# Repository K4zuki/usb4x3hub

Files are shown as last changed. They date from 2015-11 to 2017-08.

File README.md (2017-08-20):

# C92で購入いただいた方へ
- この本のPDFファイルは
  [こちら](https://github.com/K4zuki/usb4x3hub/releases/tag/c92-print-out)
- この本に登場する基板のデータは
  [こちら](https://github.com/K4zuki/usb4x3hub/releases/tag/r0.5-gerber-out)
- 秋月メモリ液晶基板の本は[こちら](https://github.com/K4zuki/AkiSpiLcd)です

# このリポジトリは何
コミケ９２に向けて書いていた本の原稿と、同時頒布を目指して設計を進めていた
基板の設計データです。原稿はmarkdownで書かれています。 設計データは
Eagle７系のbrdファイルとガーバデータです。

# USB4x3HUB: connects 4 USB hosts to share 3-port USB HUB
If you have **PCs, MACs, LINUXes, XBOXes and/or PS4s**, you can share your favorite Keyboard and Mouse (and one more)

> NOTE: I do not have PS4 so it is not tested;USB4x3HUB might not work with PS4

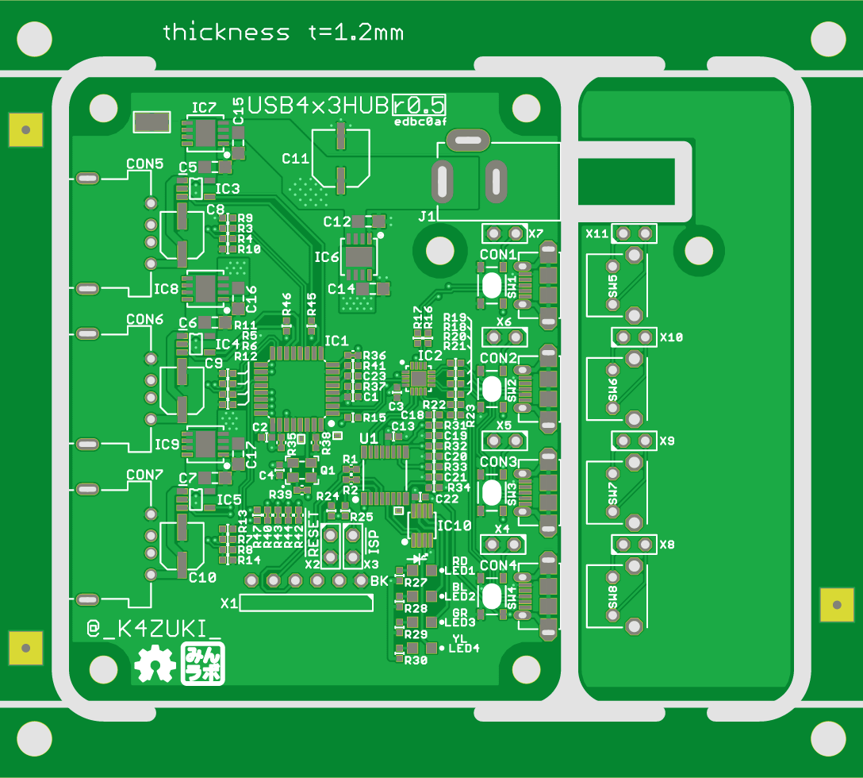
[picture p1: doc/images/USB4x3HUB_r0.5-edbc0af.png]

**rev 0.5 - みんなのラボ brand**

<!-- ![](doc/images/USB4x3HUBr1.png)
**rev 0.1** -->

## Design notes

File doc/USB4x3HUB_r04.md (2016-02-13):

| Qty | Value | Parts | Description | AKIZUKI | DIGIKEY | MOUSER | NOT_COMPONENT | SEEED |
|:---|:---|:---|:---|:---|:---|:---|:---|:---|
| 1 | TSW-106-02-S-S-RA | X1 | HEADER RIGHT ANGLE | C-05336 | 952-2372-ND | | | |
| 3 | USB A CONNECTOR | CON5-7 | USB A CONNECTOR | C-07674 | UE27AC54100-ND | | | |
| 1 | RD | LED1 | LED | I-06419 | 160-1168-1-ND | | | |
| 1 | YL | LED4 | LED | I-06420 | 160-1170-1-ND | | | |
| 1 | GR | LED3 | LED | I-06423 | 160-1169-1-ND | | | |
| 1 | BL | LED2 | LED | I-06424 | 160-1643-1-ND | | | |
| 1 | RD | SW1 | 2P tact switch | P-08213 | 679-2452-ND | | | |
| 1 | BL | SW2 | 2P tact switch | P-08214 | 679-2452-ND | | | |
| 1 | GR | SW3 | 2P tact switch | P-08215 | 679-2452-ND | | | |
| 1 | YL | SW4 | 2P tact switch | P-08216 | 679-2452-ND | | | |
| 1 | SN74LVC1G139DCUR | IC10 | single 74 logic: 139 | | 296-18235-1-ND | | | |
| 3 | 5V | IC7-9 | LDO with 4 pins | | 296-19663-1-ND | 595-TLV1117-50CDRJR | | |
| 1 | TUSB2036 | IC1 | 2/3-port USB hub IC | | 296-27129-1-ND | | | |
| 1 | 3.3V | IC6 | LDO with 4 pins | | 296-32364-1-ND | | | |
| 3 | TPS2041C | IC3-5 | power switch | | 296-35520-1-ND | | | |
| 2 | test points | TP1/2 | test points | | 36-5019CT-ND | | | |
| 10 | 0.1u/1005 | C1-4, C13, C18-22 | SMD CAPACITOR | | 490-3261-1-ND | | | 302010024 |
| 1 | 1u/1005 | C23 | SMD CAPACITOR | | 490-3890-1-ND | | | 302010040 |
| 8 | 4.7u/2012 | C5-7,C12, C14-17 | SMD CAPACITOR | | 490-9962-1-ND | | | |
| 1 | LPC812M101JDH16 | U1 | LPC81X MCU | | 568-10436-5-ND | | | |
| 1 | OSC4_6.0M | Q1 | | | CTX974CT-ND | | | |
| 1 | FSUSB74MPX | IC2 | 4 to 1 USB switch | | FSUSB74MPXCT-ND | | | |
| 6 | 1.0k/1005 | R1, R2, R27-30 | SMD resistor | | P1.00KLCT-ND | | | 301010006 |
| 1 | 1.5k/1005 | R15 | SMD resistor | | P1.50KLCT-ND | | | 301010001 |
| 20 | 10k/1005 | R24-26, R31-R47 | SMD resistor | | P10.0KLCT-ND | | | 301010047 |
| 6 | 15k/1005 | R9-14 | SMD resistor | | P15.0KLCT-ND | | | 301010042 |
| 4 | 100u/OS-CON | C8-11 | Chemical capacitor | | P16468CT-ND | | | |
| 14 | 33/1005 | R3-8, R16-23 | SMD resistor | | P33.0LCT-ND | | | 301010609 |
| 4 | USB microAB CONNECTOR | CON1-4 | USB B CONNECTOR | | WM17143CT-ND | | | |
| ----- | ----------------------- | ------------------- | ------------------------- | --------- | ----------------- | --------------------- | --------------- | ----------- |
| 1 | | GIT1 | | | | | YES | |
| 2 | | TP3/4 | test points | | | | YES | |
| 3 | | TP100-102 | test points | | | | YES | |
| 1 | OSHW | ICON1 | Silk icon of OSHW | | | | YES | |
| 1 | r0.4 | ICON2 | | | | | YES | |
| 2 | TSW-102-02-S-S | X2/3 | HEADER | | | | | |

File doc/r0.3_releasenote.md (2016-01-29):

| Part Number | USB4x3HUB_r3 | |
|:---|:---|:---|
| | Selected options: | |
| | Layer | 2 |
| | Reorder Status | -- |
| | Material Details | FR4-Standard Tg 140C |
| | Board Size (width) | 90 mm |
| | Board Size (height) | 90 mm |
| | Quantity | 10 |
| | Thickness (Finished Board) | 1.6 mm |
| | Lead Time | in 8 days |
| | Different Design in Panel | -- |
| | Route Process | -- |
| | X-out Allowance in Panel | -- |
| | Surface Finish | OSP -Organic Solderability Preservatives - RoHS |
| | Copper Weight (Finished) | 35 um |
| | Soldermask | Both Sides |
| | Soldermask | Color Green |
| | Matt Color (only add to Green or Black) | None |
| | Silkscreen Legend | 1 side |
| | Silkscreen Legend Color | White |
| | Smallest Holes | 0.30 mm |
| | Min. Tracing/Spacing | 0.15 mm |
| | Inspection Standard | IPC 2 |
| | UL Marking | No |
| | Date Code Marking | No |
| | ENIG(thicker Au) | None |
| | Peelable Soldermask | None |
| | Impedance Control | No |
| | Gold Fingers | No |
| | Gold Fingers | Chamfer None |
| | Edge Plating | None |
| | Skip V-scoring | None |
| | Carbon Mask | None |
| | Kapton tape | None |
| | Pressfit holes | None |
| | Via in pad | None |
| | Via filled with resin | None |
| | Half-cut/Castellated Holes | None |
| | Countersinks/Counterbores | None |
| | PCB specification file | USB4x3HUB.zip |
| | Last uploaded time: | 5 Jan 2016 11:30:16 |
| | Unit price | $ 6.45 |
| | Quantity | 10 |
| | Tooling cost | $ 45.88 |
| | Total | $ 110.38 |

## KNOWN ISSUE
### [ IC1/Q1 ] Q1 designed to use 48MHz _crystal_ while IC1 only requires _oscillator_(of 48MHz)
1. REMOVE C4, C21, Q1
1. cut pattern of pin29/IC1
1. cut pattern between pins 2 and 4 of Q1
1. connect pin1 and 4 of Q1 to 3.3V
1. connect pin31/IC1 to GND
1. place 6MHz Oscillator such as CTX974CT-ND(Digikey)

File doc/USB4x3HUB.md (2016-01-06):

# BOM list for `r0.3` schematic:
| #  | Parts | AKIZUKI | DIGIKEY | NOT_COMPONENT | Qty | Value |
|:--:|:---|:---|:---|:---|:----|:---|
| 1  | C1-3, C13, C20 | | 490-3261-1-ND | | 5 | 0.1u/1005 |
| 2  | C4, C21 | | 490-5858-1-ND | | 2 | 18p/1005 |
| 3  | C5-10, C12, C14-19  | | 490-9962-1-ND | | 13  | 4.7u/2012 |
| 4  | CON1-4 | | WM17143CT-ND | | 4 | USB uAB |
| 5  | IC1 | | 296-27129-1-ND | | 1 | |
| 6  | IC2 | | FSUSB74MPXCT-ND | | 1 | FSUSB74MPX |
| 7  | IC3-5 | | 296-35520-1-ND | | 3 | |
| 8  | IC6 | | AZ1117EH-3.3TRG1DICT-ND | | 1 | 3.3V |
| 9  | IC7-9 | | AZ1117EH-5.0TRG1DICT-ND | | 3 | 5V |
| 10 | IC10 | | 296-18203-1-ND | | 1 | IC\_TTL\_SINGLE\_74\_139\_FLAT |
| 11 | LED1 | (I-06419) | 754-1128-1-ND | | 1 | RD |
| 12 | LED2 | (I-06424) | 754-1794-1-ND | | 1 | BL |
| 13 | LED3 | (I-06423) | 754-1131-1-ND | | 1 | GR |
| 14 | LED4 | (I-06420) | 754-1135-1-ND | | 1 | YL |
| 15 | Q1 | | 1253-1227-1-ND | | 1 | 48M/3225 |
| 16 | R1, R2, R27-30 | | P1.00KLCT-ND | | 6 | 1k/1005 |
| 17 | R3-8, R16-23 | | P33.0LCT-ND | | 14  | 33/1005 |
| 18 | R9-14 | | P15.0KLCT-ND | | 6 | 15k/1005 |
| 19 | R15 | | P1.50KLCT-ND | | 1 | 1.5k/1005 |
| 20 | R24-26, R31-38 | | P10.0KLCT-ND | | 11  | 10k/1005 |
| 21 | TP1, TP2 | | 36-5019CT-ND | | 2 | TP_4020 |
| 22 | U1 | | 568-10436-5-ND | | 1 | LPC812M101JDH16 |
| 23 | C11 | P-05002 | | | 1 | 100u |
| 24 | CON5-7 | C-07674 | | | 3 | USB A |
| 25 | J1 | C-01604 | | | 1 | 2.5/5.5 |
| 26 | SW1 | P-08213 | | | 1 | RD |
| 27 | SW2 | P-08214 | | | 1 | BL |
| 28 | SW3 | P-08215 | | | 1 | GR |
| 29 | SW4 | P-08216 | | | 1 | YL |
| 30 | X1 | C-05336 | | | 1 | 1x6 |
| 31 | **NOT MOUNTED** | | | | | |
| 32 | X2, X3 | | | | 2 | NM,1x2 |
| 33 | **NOT COMPONENT** | | | | | |
| 34 | ICON1 | | | YES | 1 | |
| 35 | PCB1 | | | YES | 1 | PCB\_DP\_SQUARE-7X7 |
| 36 | TP100, TP101, TP102 | | | YES | 3 | |

# BOM list for `r0.1` schematic:
| Part | Value | Qty | Vendor  | Description | Link / DigiKey number |
|:---|:---|:----|:---|:---|:---|
| **AKIZUKI** | | | | | |
| C5/6/7 | 0.1uF | 3 | AKIZUKI | 1608metric MLCC | [P-05650][r01_P-05650]^[490-1524-1-ND] |
| C8/9/10/11/12/14/15/16 | 10uF | 8 | AKIZUKI | 1608metric MLCC | [P-07768][r01_P-07768] |
| CON5/6/7 | C-07674 | 3 | AKIZUKI | THROUGH-HOLE USB A connector | [C-07674][r01_C-07674] |
| J1 | C-01604 | 1 | AKIZUKI | 2.1/5.5mm DC jack | [C-01604][r01_C-01604] |
| SW1 | P-08213 (RED) | 1 | AKIZUKI | 2p tact switch | [P-08213][r01_C-08213] |
| SW2 | P-08214 (BLUE) | 1 | AKIZUKI | 2p tact switch | [P-08214][r01_C-08214] |
| SW3 | P-08215 (GREEN) | 1 | AKIZUKI | 2p tact switch | [P-08215][r01_C-08215] |
| SW4 | P-08216 (YELLOW)  | 1 | AKIZUKI | 2p tact switch | [P-08216][r01_C-08216] |
| X1 | C-01669 | 1 | AKIZUKI | 2.54 x 6p Pin-header | [C-01669][r01_C-01669] |
| X2/3 | C-08593 | 2 | AKIZUKI | 2.54 x 2p Pin-header | [C-08593][r01_C-08593] |
| **DigiKey** | | | | | |
| C1/2/3/4/13 | 0.1uF | 5 | DigiKey | 1005metric MLCC | 490-3261-1-ND |
| CON1/2/3/4 | 47589-0001 | 4 | DigiKey | MOLEX USB microAB Connector | WM17143CT-ND |
| IC1 | TUSB2036 | 1 | DigiKey | 2 or 3-port USB2.0 HUB IC | 296-27129-1-ND |
| IC2 | FSUSB74 | 1 | DigiKey | USB 1 to 4 Multiplexer | FSUSB74MPX-ND |
| IC3/4/5 | TPS2041C | 3 | DigiKey | USB current switch | 296-35520-1-ND |
| IC6 | AZ1117EH-5.0TRG1  | 1 | DigiKey | LDO for ICs 5.0V | AZ1117EH-5.0TRG1DICT-ND |
| IC7 | AZ1117EH-3.3TRG1  | 1 | DigiKey | LDO for ICs 3.3V | AZ1117EH-3.3TRG1DICT-ND |
| Q1 | 6MHz | 1 | DigiKey | Oscillator | CTX974CT-ND |
| R1/2 | 100ohm | 2 | DigiKey | 1005metric SMD resistor | P100JCT-ND |
| R3-8/16-23 | 33ohm | 14  | DigiKey | 1005metric SMD resistor | P33DDCT-ND |
| R15 | 1.5k | 1 | DigiKey | 1005metric SMD resistor | P1.5KDCCT-ND |
| R9/10/11/12/13/14 | 15k | 6 | DigiKey | 1005metric SMD resistor | P15KDECT-ND |
| U1 | LPC812M101JTB16 | 1 | DigiKey | LPC812 XSON16 package | 568-11574-1-ND |
| **Not-Components** | | | | | |
| PCB1 | PCB_DP_SQUARE-7X7 | (1) | - | Dangerous Prototypes Standard Square PCB sizes | - |
| U$1 | ICON_OSHW | (1) | - | Open Source HardWare icon | - |

[r01_P-05650]: http://akizukidenshi.com/catalog/g/gP-05650/
[r01_P-07768]: http://akizukidenshi.com/catalog/g/gP-07768/
[r01_C-07674]: http://akizukidenshi.com/catalog/g/gC-07674/
[r01_C-01604]: http://akizukidenshi.com/catalog/g/gC-01604/
[r01_C-08213]: http://akizukidenshi.com/catalog/g/gP-08213/
[r01_C-08214]: http://akizukidenshi.com/catalog/g/gP-08214/
[r01_C-08215]: http://akizukidenshi.com/catalog/g/gP-08215/
[r01_C-08216]: http://akizukidenshi.com/catalog/g/gP-08216/
[r01_C-01669]: http://akizukidenshi.com/catalog/g/gC-01669/
[r01_C-08593]: http://akizukidenshi.com/catalog/g/gC-08593/

[r02-TUSB2077A]: 296-37871-1-ND
[r02-1175-1018-ND]: 1175-1018-ND^[C-03238]
[r02-296-18203-1-ND]: 296-18203-1-ND

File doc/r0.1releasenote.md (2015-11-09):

| Part Number | USB4x3HUB | |
|:---|:---|:---|
| Selected options: | | |
| | Layer | 2 |
| | Reorder Status | -- |
| | Board Size (width) | 70 mm |
| | Board Size (height) | 70 mm |
| | Quantity | 5 |
| | Lead Time | in 5 days |
| | Different Design in Panel  | -- |
| | Route Process | -- |
| | Material Details | FR4-Standard Tg 140C |
| | Thickness (Finished Board) | 1.6 mm |
| | Surface Finish | ENIG -Electroless Nickle/Immersion Gold |
| | Soldermask | As per the file |
| | Soldermask Color | Green |
| | Copper Weight (Finished) | 35 um |
| | Silkscreen Legend | As per the file |
| | Silkscreen Legend Color | White |
| | Special Requirement Note | oval through-holes required |
| | PCB specification file | USB4x3HUB.brd |
| | Last uploaded time: | 27 Oct 2015 21:21:55 |
| Unit price | $ 15.12 | |
| Quantity | 5 | |
| Tooling cost | 0.00 | |
| Total | $ 75.60 | |

| Part Number | USB4x3HUB_stencil  | |
|:---|:---|:---|
| Selected options: | Quantity | 1 |
| | Stencil type | Non-framework |
| | Size | 150 mm * 150 mm |
| | Finished thickness | 127um |
| | Stencil side | Top Side |
| | Anti Solder Ball | Yes |
| | Send check plot | Yes |
| | Fiducials | Half lasered on board side |
| Item price | $ 0.00 | |
| Quantity | 1 | |
| Total | $ 0.00 | |

## KNOWN ISSUE
### [ IC1 ] pin24 connection to VDD makes the IC in 2-port HUB mode
* cut pattern and connect to GND instead (e.g. bridge with p23)
* fixed in r0.2

### [ IC1 ] pin32 is directly connected to VDD while the pin is output function
* cut pattern and connect by pullup resistor instead
* fixed in r0.2

### [ U1 ] U1 will not respond on SW3 and SW4 as P0_10 and 11 do not have internal pullup
* **_Critical:_ this limits number of hosts**
* fixed in r0.2

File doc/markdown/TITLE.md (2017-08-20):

# まえがき {.unnumbered}
このドキュメントは、USB機器を最大４台のホストマシンで共有するガジェット[^007]
_**USB4x3HUB**_ のソフトウェア・ハードウェアを解説する本です。

[^007]: KVMスイッチみたいなものですかってよく聞かれます。ほぼその認識で正しいです。Vはスイッチしませんけど;)

_**USB4x3HUBプロジェクト**_ は、筆者がWindowsマシンとLinuxマシン間で **USBの**
キーボードやマウスを共有できないことに不便を感じたことに端を発する
（けど当初のことを思い出せない）プロジェクトです。

この本は、_**USB4x3HUB**_ の概要及び基本的な動作の説明、ファームウェアの説明、
そしてタカチケース用パネルの寸法図を載せても『薄い本」といえる程度にまとめる
予定です。解説する基板のリビジョンは0.5です。

## 免責事項 {-}

```table
---
# caption:
alignment: C
# table-width:
markdown: True
# inline markdown
# include:
header: False
---
"この本の内容によって読者に生じたいかなる不利益についても\\
筆者は一切責任を取りません。"
```

# USB4x3HUBの概要

_**USB4x3HUB**_ の初期のプロトタイプ
はArduino形状の**mbed LPC1768**拡張基板にArduino用タッチシールド[^001]と
USBバススイッチIC[^002]をつなげ、市販のUSBハブを分解したものと秋月電子の
USBミニBコネクタDIP化キット[^004]を接続しただけの、簡素で手抜き感があるもの
でした。しかしながら近年はマイクロUSB｛ケーブル, コネクタ｝が主流になってきた
ようなので、2015年より再設計を行い、TI社の3ポートUSBハブIC[^003]と
フェアチャイルド社のUSBスイッチIC、及びスイッチ入力・USB入出力コネクタ、
それらをコントロールするmbed互換マイクロコントローラを1枚の基板に収めたものを
考案しました。

基板外形は57.0x73.0mmの縦長で、タカチの
ケース^[MX2-8-7、http://www.marutsu.co.jp/pc/i/125226/ など(650円程度)] に
ピッタリ収まります。このケースはパネル分離タイプなのでパネルを自作する
こともできます^[http://www.takachi-el.co.jp/data/pdf/2016-06-041_47-50.pdf]。

## 基本的な動作

基板上のタクトスイッチを押すとスイッチと同色の基板上のLEDが点灯します。同時にUSBバス
接続が _必ず_ 一旦切断されたあとスイッチに対応したホストコネクタと再接続
されます。同じボタンを連打するとUSB抜き差しも繰り返し起きます。

```table
---
# caption:
alignment: C
# table-width:
markdown: True
# inline markdown
# include:
header: False
---
"USBハブ側につながっているものがキーボードやマウスなら問題は少ないと思いますが、\\
USBメモリを接続した際は突然の切断に気をつける必要があります。"
```

基板上のスイッチは、DCジャックに近い方から赤青緑黄の順で
実装されています。

## r0.5での変更点 {#sec:diff-in-r0.5}
`r0.4`までは普通のタクトスイッチが実装されていましたので、ケースに入れる場合は
パネル実装タイプのスイッチを追加するなどの工作が必要でした。
`r0.5`では子基板に側面タイプのスイッチをのせ、パネルに出すことが容易になりました。
子基板との信号接続にはピンヘッダ^[http://akizukidenshi.com/catalog/g/gC-08593] と
低背ピンソケット^[http://akizukidenshi.com/catalog/g/gC-03136]を使い、10ミリ高のスペーサを
固定の補助に使います。側面スイッチは比較的入手性のよい、互換品がたくさんあるものを選定してあります。
普通のタクトスイッチのパターンも用意してありますが、未実装です。
実装が必要なときは自力で行ってください。

メイン基板の幅が`r0.4`から若干縮まって、YM-90という汎用ケースにぴったり収まるように
なりました(@sec:enclosure2)。
基板用DCジャックがUSBホスト側にツライチになっているので穴あけの手間が少なくなります。

```table
---
# caption:
alignment: C
# table-width:
markdown: True
# inline markdown
# include:
header: False
---
"このドキュメントに載っている各種図面、ガーバデータ、原稿は\\
GitHubリポジトリに用意しています。\\
<https://github.com/K4zuki/usb4x3hub.git>\\
をご参照ください。"
```

# 組み立てる前に：追加部品の購入
`r0.5`のUSB-AコネクタはUSBケーブルを指す向きが逆になっています。

```table
---
caption: 追加部品リスト
markdown: True
alignment: CCCCCC
width:
    - 0.2
    - 0.15
    - 0.15
    - 0.2
    - 0.15
    - 0.15
---
Ref,Manuf,Part,DIGIKEY,MOUSER,適用
CON 5-7,Wurth Electronics,614104150121,732-5962-1-ND,710-614104150121,`r0.5`
X 4-7,秋月,[C-03136](http://akizukidenshi.com/catalog/g/gC-03136/),NA,NA,`r0.5`
X 8-11,秋月,[C-08593](http://akizukidenshi.com/catalog/g/gC-08593/),NA,NA,`r0.5`
"スペーサ\\
両メス\\
M3x10ミリ","\\
秋月\\
",[P-07313](http://akizukidenshi.com/catalog/g/gP-07313/),NA,NA,`r0.5`
"ネジ\\
M3x6ミリ",秋月,[P-10245](http://akizukidenshi.com/catalog/g/gP-10245/),NA,NA,`r0.5`
"ロープロファイル\\
ピンソケット\\
1x4(*)",秋月,,NA,NA,`r0.5`
```
(*): 2分割するか両端2ピンを引き抜く\\

\\hrule

# 組み立てる
## ファームウェアをコンパイルする

次のページに全文を掲載しますが、かなりシンプルな実装です。
LPC812マイクロコントローラの16ピンタイプを
使いますが、[mbed.org](mbed.org)上では20ピンタイプ[^005]を
ターゲットにします。外形は異なりますがバイナリに互換性があるので20ピン用に
コンパイルされたものでも16ピン版で実行できます。

<https://developer.mbed.org/users/k4zuki/code/usb4x3hub/> が実際のリポジトリです。

\\newpage
```listingtable
source: ../mbed/main.cpp
class: cpp
tex: True
---
```

## ファームウェアを書き込む

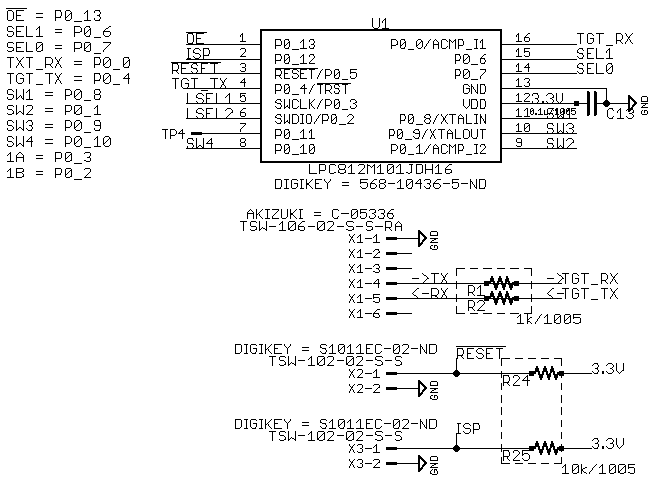
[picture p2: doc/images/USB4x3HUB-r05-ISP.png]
回路図(マイコン部分を拡大)


書込みはFTDIケーブルなどのUSB−UART変換ケーブルとLPC21ISP、あるいはmbed LPC1768と
**_イカ醤油ポッポ焼き_**^[https://developer.mbed.org/users/okano/code/ika_shouyu_poppoyaki/] で行います。
イカ醤油ポッポ焼きを行うときの接続表は以下のようになります。USB4x3HUBは予め電源を入れておきます。

ソースをオンラインコンパイラ上でLPC800-MAX向けにコンパイルし、ダウンロードした _usb4x3hub.bin_
を _bin_ にリネームしてLPC1768にコピーします。

```table
---
caption: イカ醤油ポッポ焼き接続表
markdown: True
---
mbed LPC1768,Function,USB4x3HUB
VOUT,3.3V supply,
GND,GND,X1-1
p25,ISP enable,X3-1
p26,UART (RX)<-(TX),X1-5
p27,UART (TX)->(RX),X1-4
p28,RESET,X2-1
```

\\newpage
## エンクロージャ（ケース）を用意する
エンクロージャ（ケース）は、頒布しません。代わりにアイデアを３点提示します。
いずれもアクリル（など）の加工が必要です。TechShopやDMM.Makeなどの工作室
を利用するなどして適宜合わせこんで自作してください。

### アイデア１：市販のケースを購入し工夫する（１）
タカチのケース"MX2-8-7??(??は色コード)"を使用します。ケースは上下の
パーツとパネルで構成されています。パネル部品の固定にはケースに付属している
タッピングネジを使うか、M3のタップを立てるなどもよく行われているようです。
筆者はその手の加工は苦手なのでアクリル加工と付属タッピングネジで
済ませました。
```table
---
# caption:
alignment: C
# table-width:
markdown: True
# inline markdown
# include:
header: False
---
付録に基板及びパネルの寸法図を載せますので参考にしてください
```

#### パネルの穴あけ加工
前後のパネルにUSBコネクタの穴を空けます。デバイス（ハブ）側は穴が大きめで比較的加工が簡単です。
ホスト側はコネクタとスイッチの穴、DCジャックのための角穴を開けます。

穴あけの方法は、付属品のパネルにがんばって手加工をするか、アクリル加工サービスなどを利用するか、
ケースメーカー（今回はタカチ）に加工を依頼するなどを提案しときます。

#### 追加で必要になる部品

```table
---
caption: 部品表
markdown: True
alignment: DDCCC
width:
    - 0.35
    - 0.35
    - 0.1
    - 0.1
    - 0.1
---
部品,型番,個数,入手先,URL
ケース,MX-2-8-7BB,1,マルツ,[125226](http://www.marutsu.co.jp/pc/i/125226/)
"ACアダプタ9V/0.65A",GF06-US09065A,1,秋月,[M-03681](http://akizukidenshi.com/catalog/g/gM-03681/)
```

スイッチはaitendoまたはマルツ（デジキーからの取り寄せ）、
ケースは千石（取り寄せ）かマルツ（秋葉原本店なら *運が良ければ* 店頭にある）で購入できます。

### アイデア２：市販のケースを購入し工夫する（２） {#sec:enclosure2}
タカチのYM-90というメタルシャーシも使えます。千石・マルツ・共立などで買える定番品です。
MX2-8-7よりもUSB面の幅に余裕があるので固定方法に工夫がいります。
コネクタ面の穴あけはよりめんどくさそうなのでメーカに加工を依頼するのが最短と思われます。

### アイデア３：アクリル板を切り出して組み合わせる
アクリルレーザ加工で６面全てとそれらのジョイントのためにブロックスペーサ
を入手して組み合わせるという手も考えられます。
アクリルを例にしていますが材料はなんでもいいと思います。

#### アクリル加工
６面分切ります。側面板は全面無加工が１枚と、ファームウェア書込みピンヘッダの穴
をあけたものが１枚（予め書き込んでおけば穴あけ不要）、
底面板と天板は四隅のネジ穴だけ、前後パネルはUSB用を各々開け、 _いい感じに_ 組み合わせます。

#### 追加で必要になる部品

```table
---
caption: 部品表
markdown: True
alignment: DDCCC
width:
    - 0.3
    - 0.2
    - 0.1
    - 0.3
    - 0.1
---
部品,型番,個数,入手先,URL
ACアダプタ9V/0.65A,GF06-US09065A,1,秋月 ,[M-03681](http://akizukidenshi.com/catalog/g/gM-03681/)
M3x6mmネジ,,"30\\
(概算)",秋月など,[P-10245](http://akizukidenshi.com/catalog/g/gP-10245/)
"ブロックスペーサ\\
8mm角6方向M3タッピング","\\
CB3-8-Z\\
",8,秋月,[P-07466](http://akizukidenshi.com/catalog/g/gP-07466/)
基板用DCジャック,2DC0005D100,1,秋月,[C-01604](http://akizukidenshi.com/catalog/g/gC-01604/)
自作アクリルケース,,1 set,アクリル加工サービスなど,
```

ほぼ全て秋月のみで揃います。

# 付録
リビジョン0.5の基板の各データを載せておきます。元になったデータはGitHubリポジトリに置いてあります(@sec:diff-in-r0.5)。

## 回路図
\\newpage
```rotate
source: images/USB4x3HUB_r0.5-edbc0af-sch.png
angle: 90
# title: 'Alt title'
caption: 回路図
attr:
#  width: 80%
#  height: 50%
---
```
<!-- `images/USB4x3HUB-r0.5-edbc0af-sch.png`{.rotate .caption="回路図" .angle=90}{} -->

\\newpage
## 基板図

```rotate
source: images/USB4x3HUB_r0.5-edbc0af.png
angle: 90
# title: 'Alt title'
caption: 基板外観図
attr:
#  width: 80%
#  height: 50%
---
```
<!-- ![基板外観図](images/USB4x3HUB-r0.5-edbc0afpng){} -->
\\newpage
## BOMリスト
DCジャック以外は全部Digikeyで購入できます。Digikey品番をMouserで検索すると
Mouserの商品ページに飛べるらしいです。

```table
---
caption: BOMリスト(r0.5)
include: data/BOM-r0.5.csv
markdown: True
---
```

\\newpage
## 基板寸法とパネル寸法の例
基板外形、DCジャックなどの開口部の位置寸法とMX2-8-7のパネル寸法図面を
兼ねています。

\\newpage
```rotate
source: images/USB4x3HUB_r0.5-edbc0af-meas.png
angle: 90
# title: 'Alt title'
caption: 寸法図
attr:
#  width: 80%
#  height: 50%
---
```
<!-- `images/USB4x3HUB_r04-a30fd1f_meas.png`{.rotate .caption="寸法図" .angle=90}{} -->

# 更新履歴 {.unnumbered}
## Revision 1.0(C91) {.unnumbered}
- 最初の発行。やばみ
- 新基板落ちた（未発送@12月24日）
- それでも本だけだしておく暴挙（）
- キンコーズでオンライン注文の予定だけど落ちるかも（）

## Revision 2.0(C92) {.unnumbered}
- 改訂。やばみ
- 表紙絵にはいらすとやさんのフリー素材を使用、ポンチ絵感ある
- `r0.4`に関連する記述を削除
- C91に間に合わなかった例の新基板（`r0.4`）は部品選定バグありだったので結果オーライ（）
- 基板はC92に間に合った（実装が間に合ったとは言っていない）
- 書いてる間もTLの諸兄のマサカリ()を受け基板リビジョンが微妙に上がっていってます()。BOMと基板図の
  微妙な違いなどはご容赦ください()

<!--  -->
[^001]: https://www.switch-science.com/catalog/1966/
[^002]: https://www.fairchildsemi.com/datasheets/FS/FSUSB74.pdf
[^003]: http://www.ti.com/lit/ds/symlink/tusb2036.pdf
[^004]: http://akizukidenshi.com/catalog/g/gK-05258/
[^005]: https://developer.mbed.org/platforms/NXP-LPC800-MAX/
[^006]: https://www.e-switch.com/system/asset/product_line/data_sheet/37/LP1.pdf

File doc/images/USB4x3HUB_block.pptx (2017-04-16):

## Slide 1

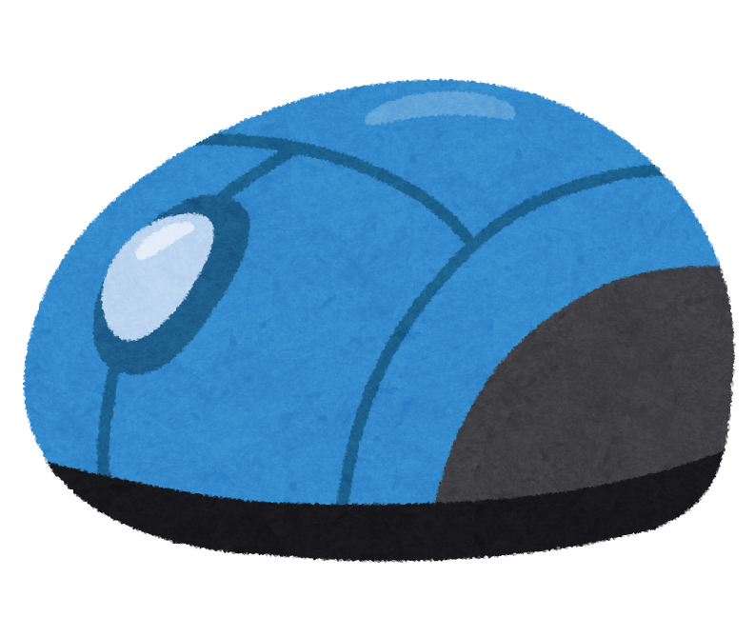
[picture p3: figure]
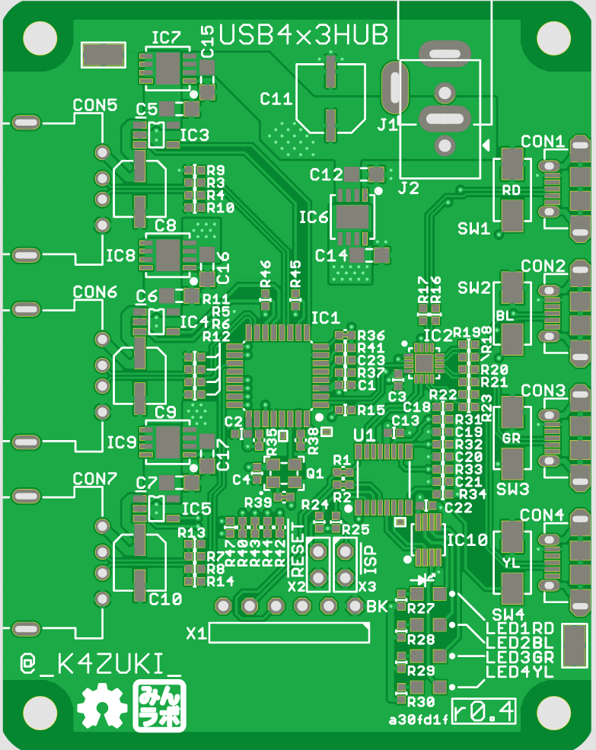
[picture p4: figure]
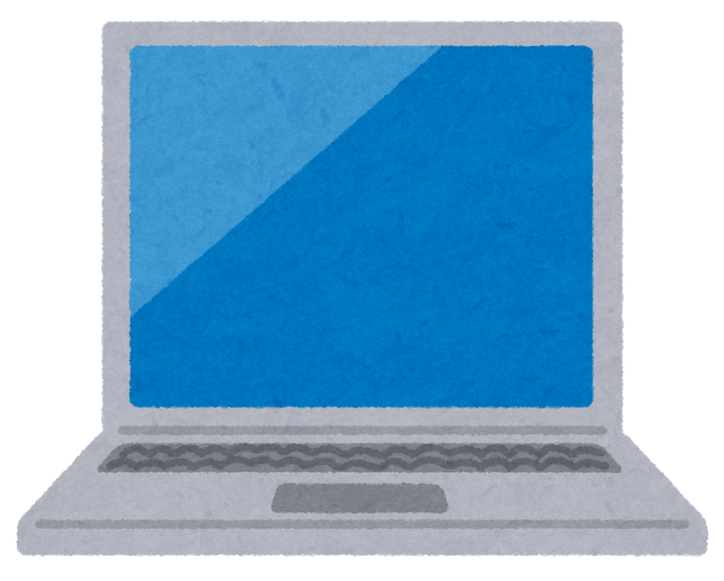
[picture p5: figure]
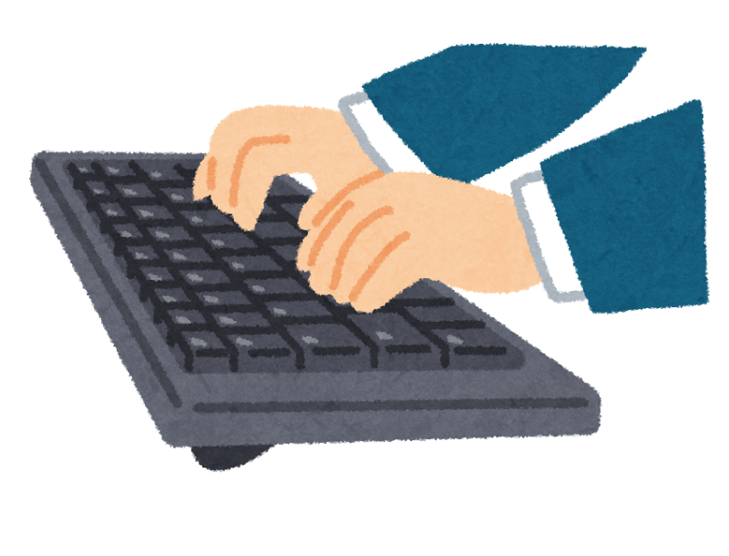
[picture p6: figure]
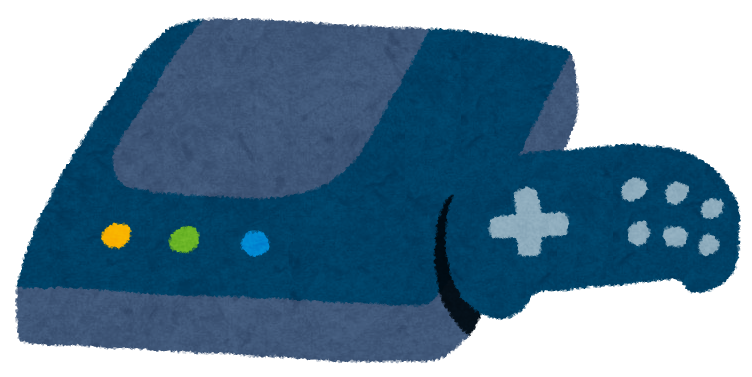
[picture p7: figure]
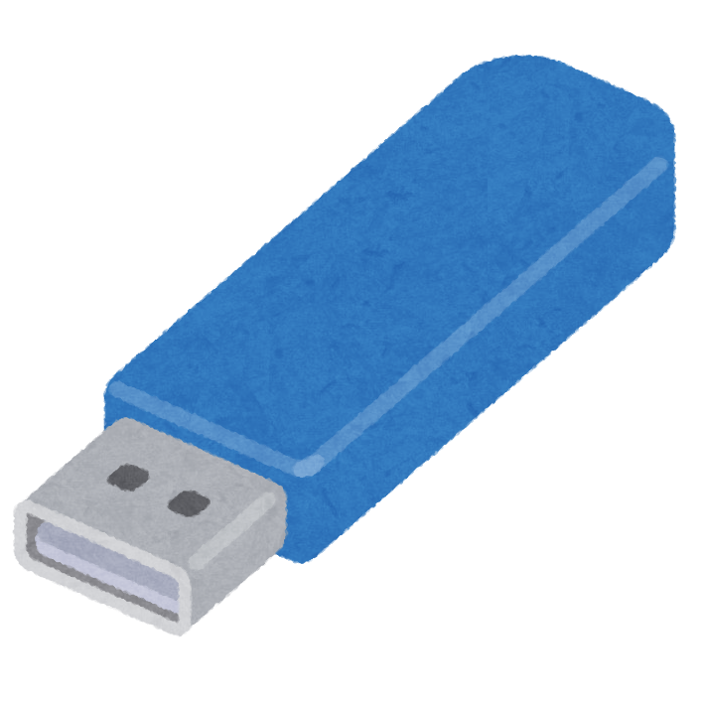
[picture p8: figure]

PC

Mac

一部
ゲーム機

4 USB hosts
x
3-Port USB hub

ラズパイ

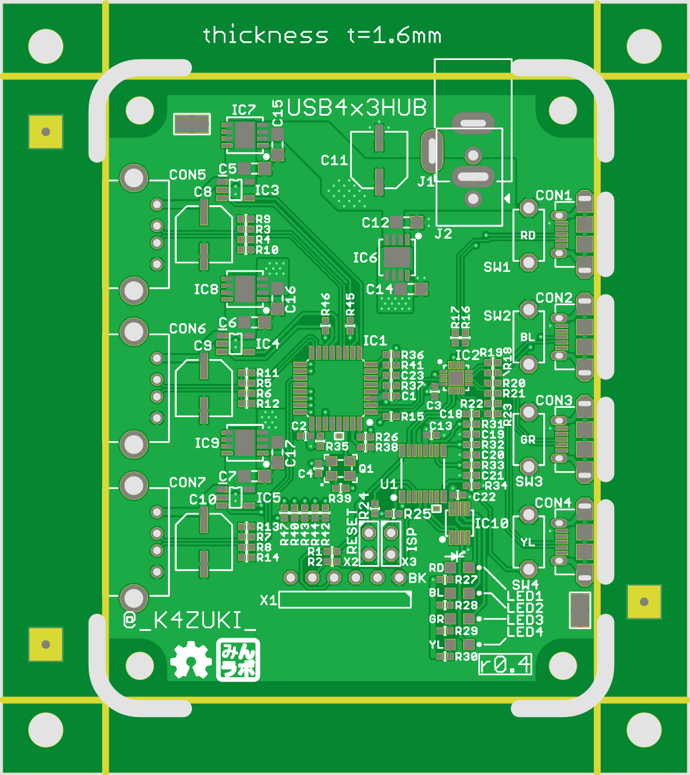
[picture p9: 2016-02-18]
doc/images/USB4x3HUB_r0.4.png

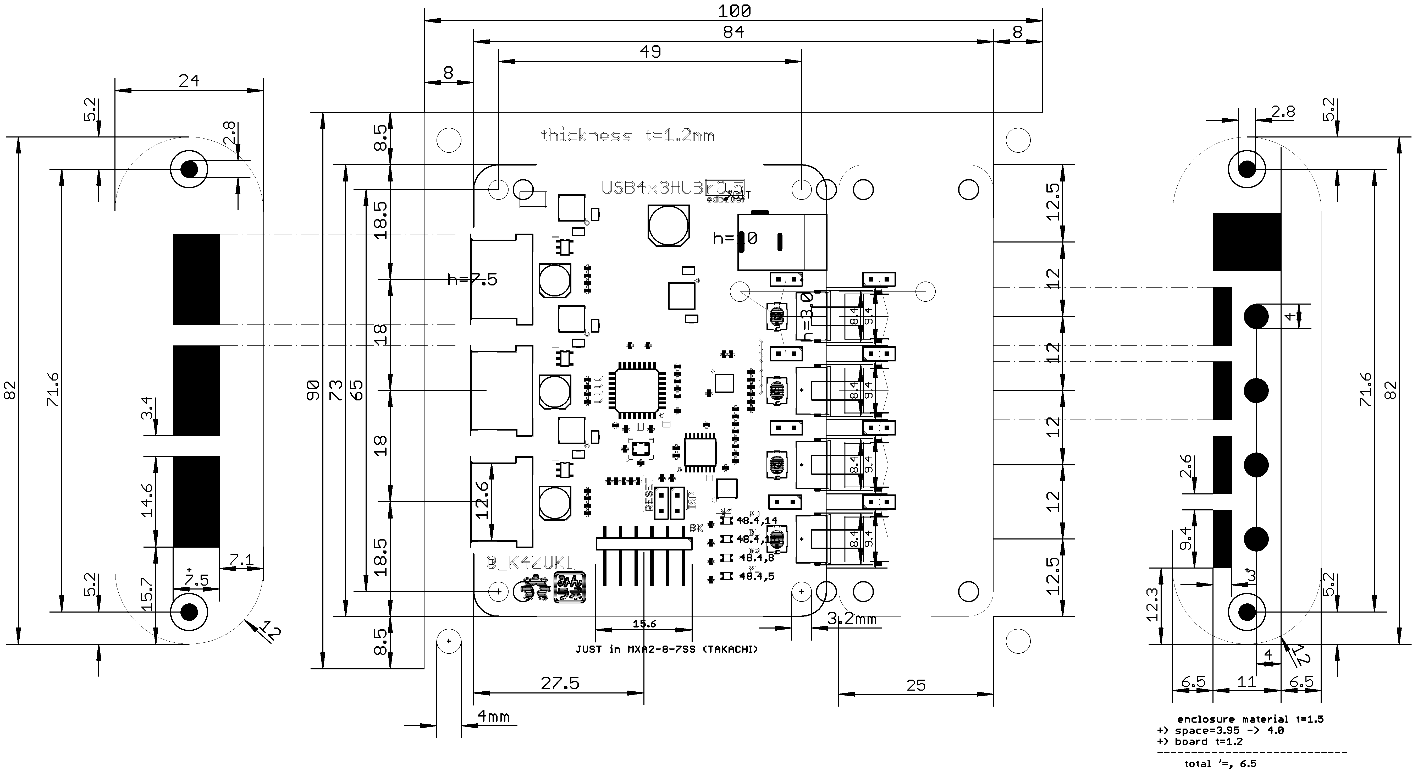
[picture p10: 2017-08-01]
doc/images/USB4x3HUB_r0.5-edbc0af-meas.png

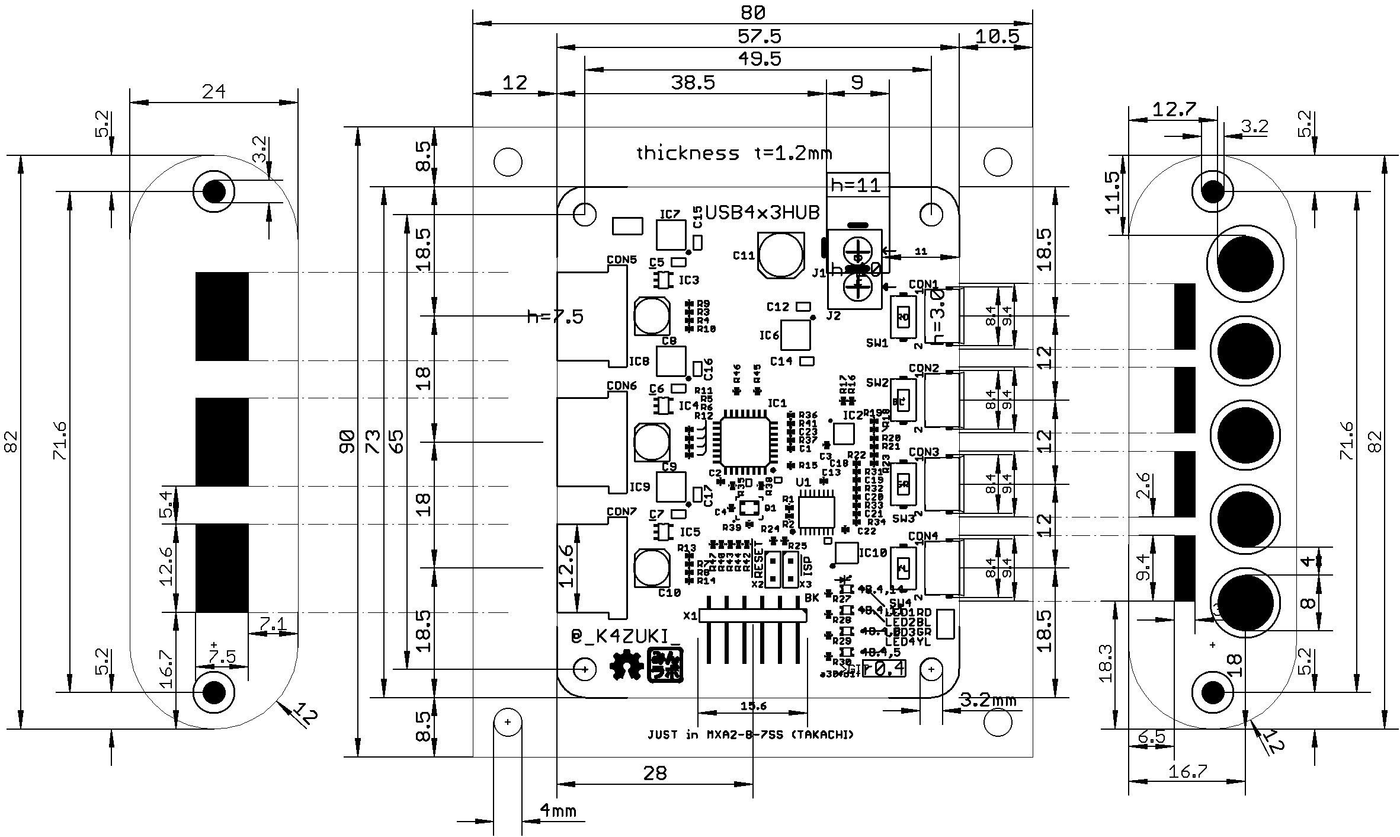
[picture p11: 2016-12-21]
doc/images/USB4x3HUB_r04-a30fd1f_meas.png

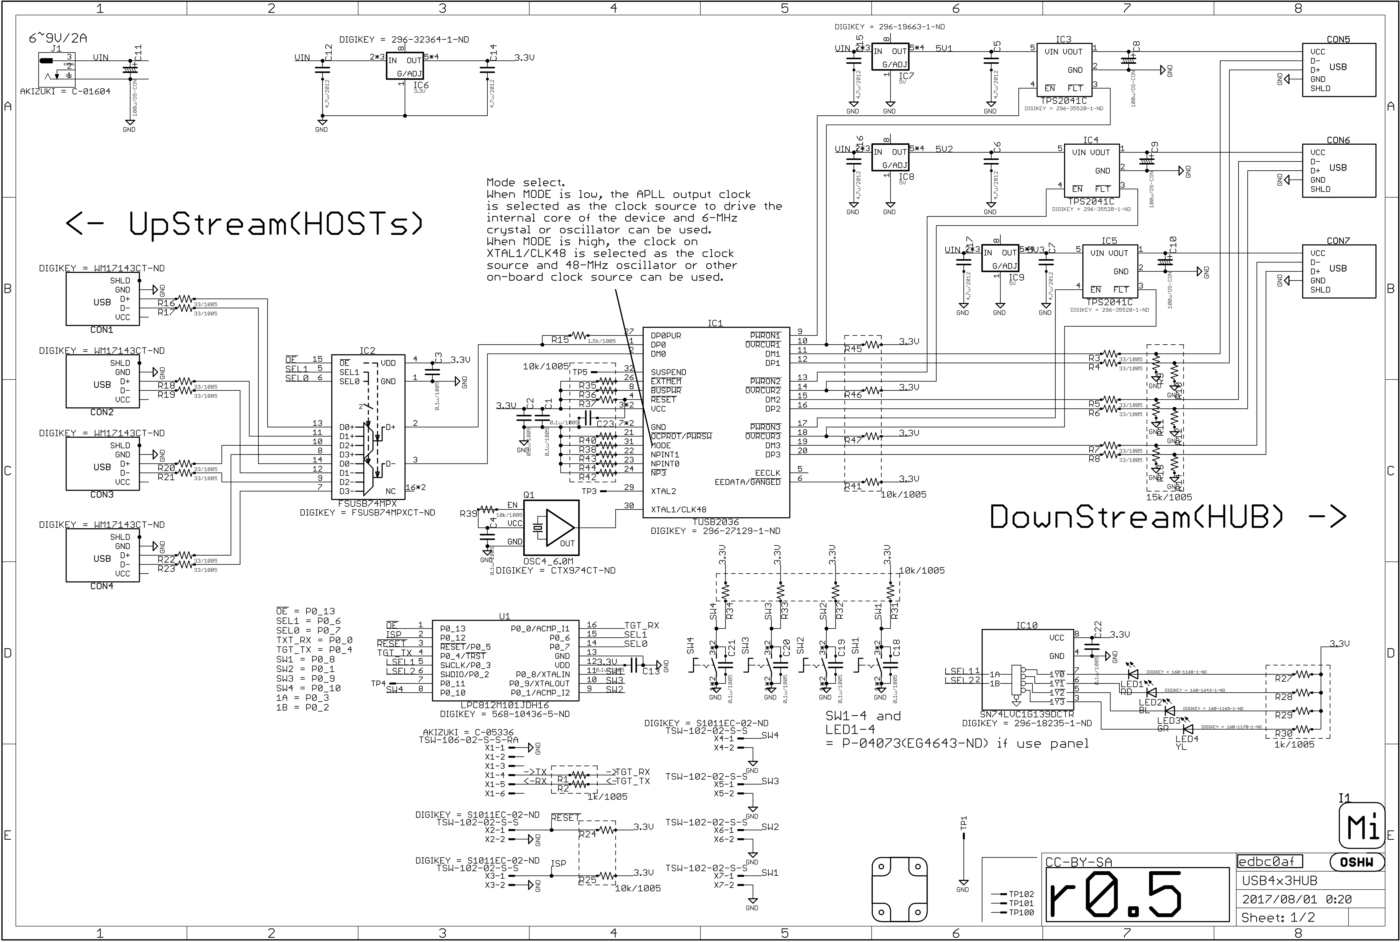
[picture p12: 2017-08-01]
doc/images/USB4x3HUB_r0.5-edbc0af-sch.png

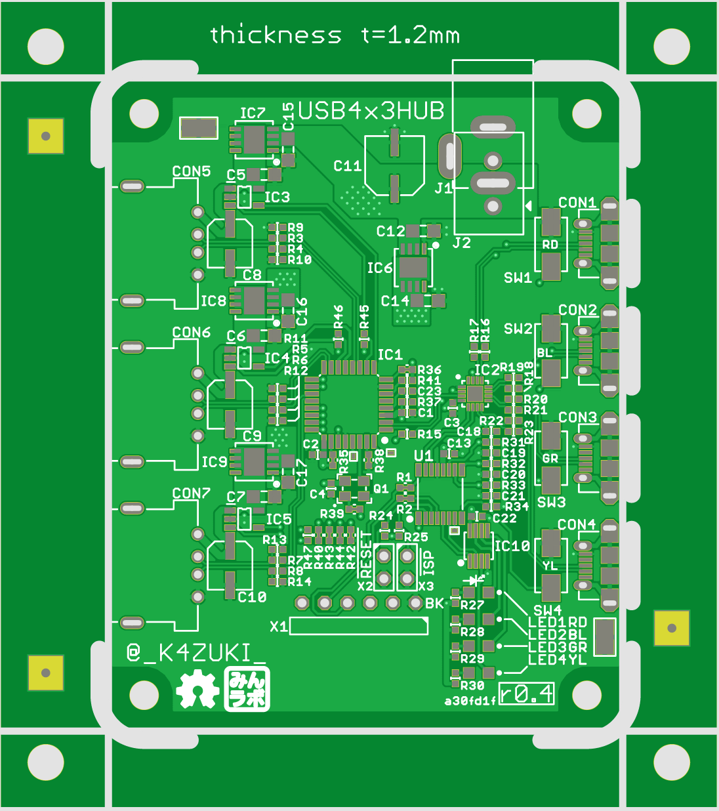
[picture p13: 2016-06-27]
doc/images/USB4x3HUB_r04-a30fd1f.png

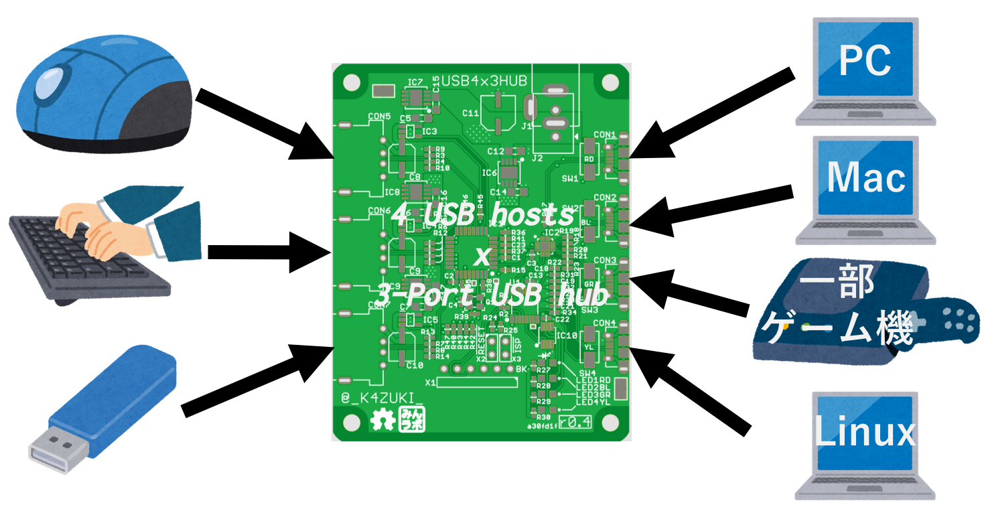
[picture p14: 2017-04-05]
doc/images/USB4x3HUB-block.png

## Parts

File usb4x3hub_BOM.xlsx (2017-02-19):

Qty | Value | Device | Package | Parts | Description | AKIZUKI | DIGIKEY | MOUSER | NOT_COMPONENT | SEEED | SMD_PAD | TH_PAD | SMD_TOTAL | TH_TOTAL
1 |  | TESTPAD_4020 | TP_4020 | TP1 | test points |  | 36-5019CT-ND |  |  |  | 1 |  | 1 | 0
4 |  | CON_USB_UB | CON_USB_47589-0001MOLEX | CON1, CON2, CON3, CON4 | USB B CONNECTOR |  | WM17143CT-ND |  |  |  | 11 |  | 44 | 0
1 | LPC812M101JDH16 | IC_LPC81X_16_JDH16 | SOT65P510X450X110-16N | U1 | LPC81X microcontroller |  | 568-10436-5-ND |  |  |  | 16 |  | 16 | 0
1 | FSUSB74MPX | IC_USB_FSUSB74 | QFN16_0.5P3.0X3.0 | IC2 | 4 to 1 USB switch |  | FSUSB74MPXCT-ND |  |  |  | 17 |  | 17 | 0
11 | 0.1u/1005 | C_SMD_0.1U_1005 | C0402 | C1, C2, C3, C4, C13, C18, C19, C20, C21, C22, C23 | SMD CAPACITOR |  | 490-3261-1-ND |  |  | 302010024 | 2 |  | 22 | 0
1 | 1.5k/1005 | R_US_1.5K_1005 | C0402 | R15 | SMD resistor |  | P1.50KLCT-ND |  |  | 301010001 | 2 |  | 2 | 0
1 | 100u/OS-CON | C_DENKAI_100U_2.5P6.3_C6 | C_2.5PHI6.3_C6 | C11 | Chemical capacitor |  | P16468CT-ND |  |  |  | 2 |  | 2 | 0
3 | 100u/OS-CON | C_DENKAI_100U_875105142005WURTH | C_2.5PHI5_875105142005WURTH | C8, C9, C10 | Chemical capacitor |  | 732-6394-1-ND |  |  |  | 2 |  | 6 | 0
11 | 10k/1005 | R_US_10K_1005 | C0402 | R24, R25, R31, R32, R33, R34, R37, R41, R45, R46, R47 | SMD resistor |  | P10.0KLCT-ND |  |  | 301010047 | 2 |  | 22 | 0
6 | 15k/1005 | R_US_15K_1005 | C0402 | R9, R10, R11, R12, R13, R14 | SMD resistor |  | P15.0KLCT-ND |  |  | 301010042 | 2 |  | 12 | 0
4 | 1k/1005 | R_US_1.0K_1005 | C0402 | R27, R28, R29, R30 | SMD resistor |  | P1.00KLCT-ND |  |  | 301010006 | 2 |  | 8 | 0
14 | 33/1005 | R_US_33R_1005 | C0402 | R3, R4, R5, R6, R7, R8, R16, R17, R18, R19, R20, R21, R22, R23 | SMD resistor |  | P33.0LCT-ND |  |  | 301010609 | 2 |  | 28 | 0
8 | 4.7u/2012 | C_SMD_4.7U_2012 | CR_2125 | C5, C6, C7, C12, C14, C15, C16, C17 | SMD CAPACITOR |  | 490-9962-1-ND |  |  |  | 2 |  | 16 | 0
1 | BL | LEDBLCHIPLED_0805 | CHIPLED_0805 | LED2 | LED | I-06424 | 160-1643-1-ND |  |  | 304090061 | 2 |  | 2 | 0
1 | BL | TACTSW2_FSM2JMTR | SW_TACTSW_FSM2JMTR | SW2 | 2P tact switch |  | 450-2146-1-ND |  |  |  | 2 |  | 2 | 0
1 | GR | LEDGRCHIPLED_0805 | CHIPLED_0805 | LED3 | LED | I-06423 | 160-1169-1-ND |  |  | 304090057 | 2 |  | 2 | 0
1 | GR | TACTSW2_FSM2JMTR | SW_TACTSW_FSM2JMTR | SW3 | 2P tact switch |  | 450-2146-1-ND |  |  |  | 2 |  | 2 | 0
1 | RD | LEDRDCHIPLED_0805 | CHIPLED_0805 | LED1 | LED | I-06419 | 160-1168-1-ND |  |  | 304090046 | 2 |  | 2 | 0
1 | RD | TACTSW2_FSM2JMTR | SW_TACTSW_FSM2JMTR | SW1 | 2P tact switch |  | 450-2146-1-ND |  |  |  | 2 |  | 2 | 0
1 | YL | LEDYLCHIPLED_0805 | CHIPLED_0805 | LED4 | LED | I-06420 | 160-1170-1-ND |  |  | 304090039 | 2 |  | 2 | 0
1 | YL | TACTSW2_FSM2JMTR | SW_TACTSW_FSM2JMTR | SW4 | 2P tact switch |  | 450-2146-1-ND |  |  |  | 2 |  | 2 | 0
1 | TUSB2036 | IC_USB_TUSB2036 | QFP32_0.8P7.2X7.2 | IC1 | 2/3-port USB hub IC |  | 296-27129-1-ND |  |  |  | 32 |  | 32 | 0
1 | OSC4_6.0M | OSC4_6.0M | CLOCK_2520 | Q1 |  |  | CTX974CT-ND |  |  |  | 4 |  | 4 | 0
3 | TPS2041C | IC_POWER_TPS2041C | IC_05_0.95_50MIL | IC3, IC4, IC5 | power switch |  | 296-35520-1-ND |  |  |  | 5 |  | 15 | 0
1 | SN74LVC1G139DCTR | IC_TTL_SINGLE_74_139_FLAT | SOT65P315X290-8N | IC10 | single 74 logic IC: 139 |  | 296-18235-1-ND |  |  |  | 8 |  | 8 | 0
1 | 3.3V | LDO4_3.3_DRJ | DFN80P410X410_8N | IC6 | LDO with 4 pins |  | 296-32364-1-ND |  |  |  | 9 |  | 9 | 0
3 | 5V | LDO4_5.0_DRJ | DFN80P410X410_8N | IC7, IC8, IC9 | LDO with 4 pins |  | 296-19663-1-ND | 595-TLV1117-50CDRJR |  |  | 9 |  | 27 | 0
1 |  | CON_DCJACK_C1604 | CON_DCJACK_C-1604 | J1 | DC JACK : 2.1 / 2.5 mm | C-01604 |  | 163-179PH-EX |  | 320120003 |  | 3 | 0 | 3
3 |  | CON_USB_A_614104150121 | CON_USB_614104150121WURTH | CON5, CON6, CON7 | USB B CONNECTOR |  | 732-5962-1-ND | 710-614104150121 |  |  |  | 6 | 0 | 18
1 | TSW-106-02-S-S-RA | TSW-106-02-S-S-RA | TSW-106-02-S-S-RA | X1 | THROUGH-HOLE HEADER | C-05336 | 952-2372-ND |  |  | 320020019 |  | 6 | 0 | 6
2 | TSW-102-02-S-S | TSW-102-02-S-S | TSW-102-02-S-S | X2, X3 | THROUGH-HOLE POST HEADER |  | S1011EC-02-ND |  | YES | 320020016 |  | 2 | 0 | 4
1 |  | ICON_MINLAB_5.2S | ICON_MINLAB_5.2MM | I1 |  |  |  |  | YES |  |  |  | 307 | 31
4 |  | PCB_CORNER | PCB_CORNER | P1, P2, P3, P4 |  |  |  |  | YES
9 |  | R_US__1005SHORT | R0402SHORT | R1, R2, R35, R36, R38, R40, R42, R43, R44 | SMD resistor |  |  |  | YES
3 |  | TESTPAD | TP06RECT | TP3, TP4, TP5 | test points |  |  |  | YES
3 |  | TESTPAD_F | FIDUCIAL | TP100, TP101, TP102 | test points |  |  |  | YES
1 | 10k/1005 | R_US__1005SHORT | R0402SHORT | R39 | SMD resistor |  |  |  | YES
1 | 7236034 | GIT-REVISION_1.0 | GIT-REVISION | GIT1 |  |  |  |  | YES
1 | OSHW | ICON_OSHW | ICON_OSHW | ICON1 | Silk icon of OSHW |  |  |  | YES
1 | r0.5 | ICON_REVISION_2.0 | ICON_REVISION2.0 | ICON2 |  |  |  |  | YES

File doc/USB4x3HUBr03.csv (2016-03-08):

Parts | AKIZUKI | DIGIKEY | NOT_COMPONENT | Qty | Value | Device | Package | Description
Q1 |  | 1253-1227-1-ND |  | 1 | 48M/3225 | CRYSTAL4_48M_3225 | CLOCK_3225
IC10 |  | 296-18203-1-ND |  | 1 | IC_TTL_SINGLE_74_139_FLAT | IC_TTL_SINGLE_74_139_FLAT | SOT65P315X290-8N
IC1 |  | 296-27129-1-ND |  | 1 |  | IC_USB_TUSB2036 | QFP32_0.8P7.2X7.2
IC3, IC4, IC5 |  | 296-35520-1-ND |  | 3 |  | IC_POWER_TPS2041C | IC_05_0.95_50MIL
C1, C2, C3, C13, C20 |  | 490-3261-1-ND |  | 5 | 0.1u/1005 | C_SMD_0.1U_1005 | C0402 | SMD CAPACITOR : PAD - PAD
C4, C21 |  | 490-5858-1-ND |  | 2 | 18p/1005 | C_SMD_18P_1005 | C0402 | SMD CAPACITOR : PAD - PAD
C5, C6, C7, C8, C9, C10, C12, C14, C15, C16, C17, C18, C19 |  | 490-9962-1-ND |  | 13 | 4.7u/2012 | C_SMD_4.7U_2012 | CR_2125 | SMD CAPACITOR : PAD - PAD
U1 |  | 568-10436-5-ND |  | 1 | LPC812M101JDH16 | IC_LPC81X_16_JDH16 | SOT65P510X450X110-16N
IC6 |  | AZ1117EH-3.3TRG1DICT-ND |  | 1 | 3.3V | LDO4_3.3_SOT223 | IC_SOT223
IC7, IC8, IC9 |  | AZ1117EH-5.0TRG1DICT-ND |  | 3 | 5V | LDO4_5.0_SOT223 | IC_SOT223
IC2 |  | FSUSB74MPX-ND |  | 1 |  | IC_USB_FSUSB74 | QFN16_0.5P3.0X3.0
R1, R2, R27, R28, R29, R30 |  | P1.00KLCT-ND |  | 6 | 1k/1005 | R_US_1.0K_1005 | C0402 | R_US_PAD_PAD : SMD R PAD is NTH-NTH
R15 |  | P1.50KLCT-ND |  | 1 | 1.5k/1005 | R_US_1.5K_1005 | C0402 | R_US_PAD_PAD : SMD R PAD is NTH-NTH
R24, R25, R26, R31, R32, R33, R34, R35, R36, R37, R38 |  | P10.0KLCT-ND |  | 11 | 10k/1005 | R_US_10K_1005 | C0402 | R_US_PAD_PAD : SMD R PAD is NTH-NTH
R9, R10, R11, R12, R13, R14 |  | P15.0KLCT-ND |  | 6 | 15k/1005 | R_US_15K_1005 | C0402 | R_US_PAD_PAD : SMD R PAD is NTH-NTH
R3, R4, R5, R6, R7, R8, R16, R17, R18, R19, R20, R21, R22, R23 |  | P33.0LCT-ND |  | 14 | 33/1005 | R_US_33R_1005 | C0402 | R_US_PAD_PAD : SMD R PAD is NTH-NTH
CON1, CON2, CON3, CON4 |  | WM17143CT-ND |  | 4 |  | CON_USB_UB | CON_USB_47589-0001MOLEX | USB B CONNECTOR
J1 | C-01604 |  |  | 1 | 2.5/5.5 | CON_DCJACK_C1604 | CON_DCJACK_C-1604 | DC JACK : 2.1 / 2.5 mm
X1 | C-05336 |  |  | 1 | 1x6 | TSW-106-02-S-S-RA | TSW-106-02-S-S-RA | THROUGH-HOLE .025" SQ POST HEADER
CON5, CON6, CON7 | C-07674 |  |  | 3 |  | CON_USB_A | CON_USB_A_SHIELD | USB B CONNECTOR
LED1 | I-06419 |  |  | 1 | RD | LEDRDCHIPLED_0805 | CHIPLED_0805 | LED
LED4 | I-06420 |  |  | 1 | YL | LEDYLCHIPLED_0805 | CHIPLED_0805 | LED
LED3 | I-06423 |  |  | 1 | GR | LEDGRCHIPLED_0805 | CHIPLED_0805 | LED
LED2 | I-06424 |  |  | 1 | BL | LEDBLCHIPLED_0805 | CHIPLED_0805 | LED
C11 | P-05002 |  |  | 1 | 100u | C_DENKAI_100U_2.5P5 | C_2.5PHI5 | (Device name) : (Main function of the device)
SW1 | P-08213 |  |  | 1 | RD | TACTSW2_RD_P807X | SW_TACTSW_P8073
SW2 | P-08214 |  |  | 1 | BL | TACTSW2_BL_P807X | SW_TACTSW_P8073
SW3 | P-08215 |  |  | 1 | GR | TACTSW2_GR_P807X | SW_TACTSW_P8073
SW4 | P-08216 |  |  | 1 | YL | TACTSW2_YL_P807X | SW_TACTSW_P8073
ICON1 |  |  | YES | 1 |  | ICON_OSHW | ICON_OSHW
TP100, TP101, TP102 |  |  | YES | 3 |  | TESTPAD_F | FIDUCIAL
TP1, TP2 |  |  | YES | 2 | TPPAD1-13 | TPPAD1-13 | P1-13 | Test pad
PCB1 |  |  | YES | 1 | PCB_DP_SQUARE-7X7 | PCB_DP_SQUARE-7X7 | DP7070_V1 | Dangerous Prototypes Standard Square PCB sizes
X2, X3 |  |  |  | 2 | NM,1x2 | TSW-102-02-S-S | TSW-102-02-S-S | THROUGH-HOLE .025" SQ POST HEADER

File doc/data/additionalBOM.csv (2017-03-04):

Ref | Manuf | Part | DIGIKEY | MOUSER | 適用
CON 5-7 | Wurth Electronics | 614104150121 | 732-5962-1-ND | 710-614104150121 | `r0.5`
CON 5-7 | aitendo | UAF-99 | NA | NA | `r0.4`

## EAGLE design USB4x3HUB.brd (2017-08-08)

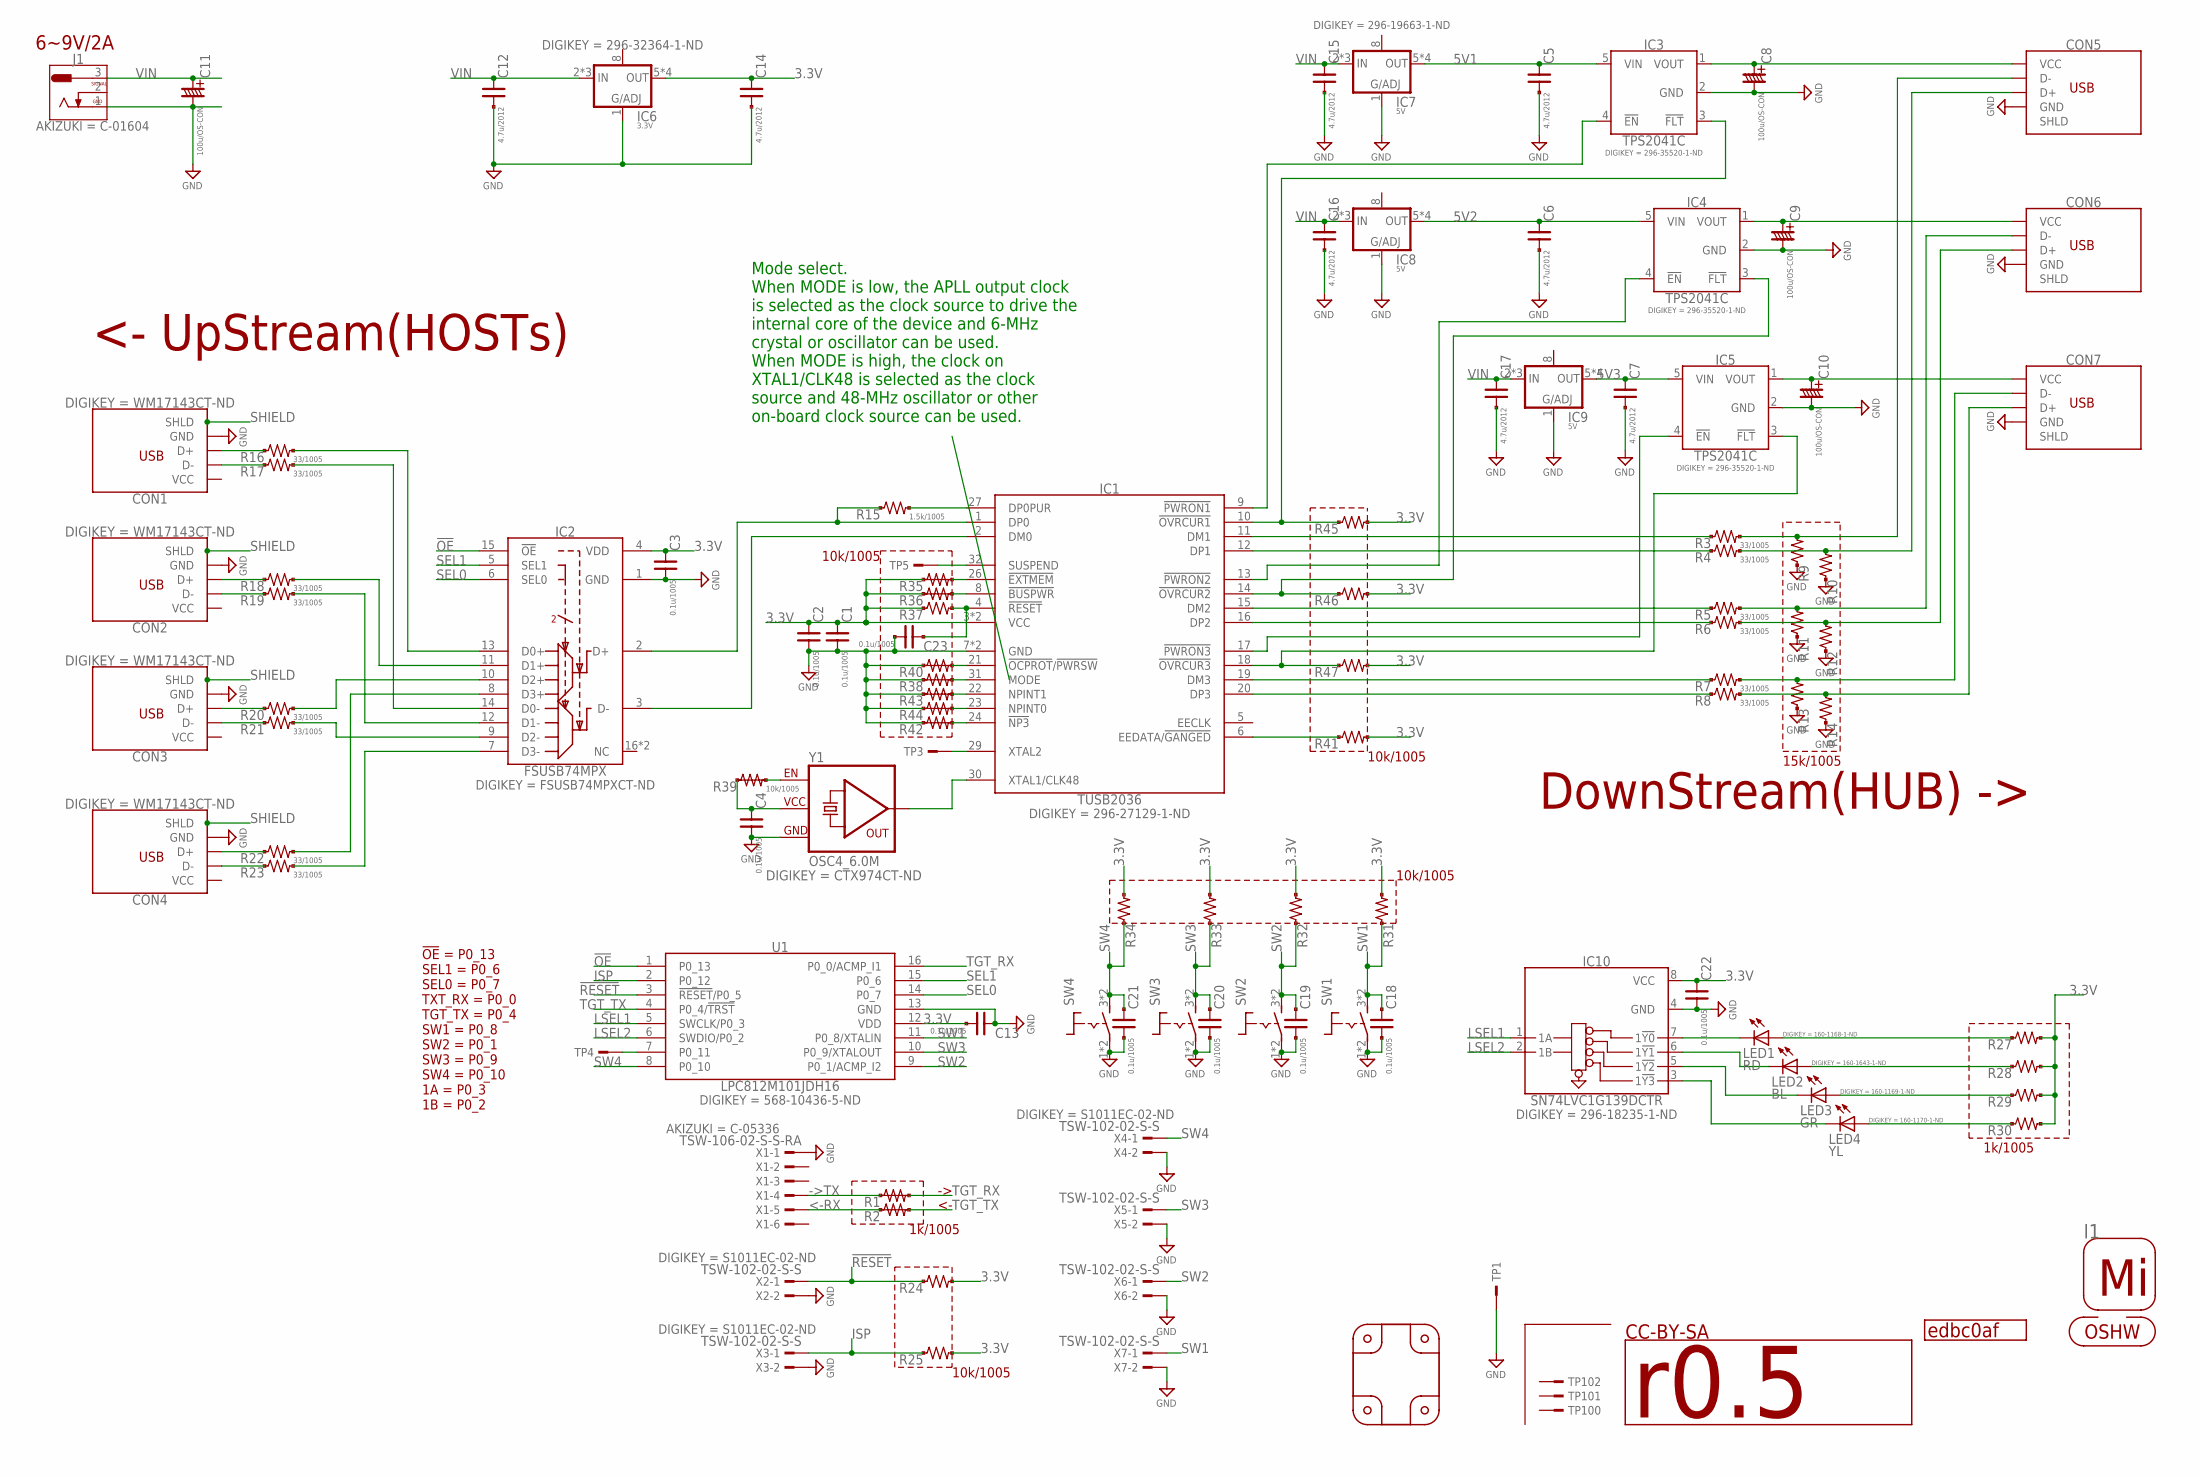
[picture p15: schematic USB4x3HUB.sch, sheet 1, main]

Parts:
C1, C2, C3, C4, C13, C18, C19, C20, C21, C22, C23: 0.1u/1005; C0402
C5, C6, C7, C12, C14, C15, C16, C17: 4.7u/2012; CR_2125
C8, C9, C10: 100u/OS-CON; C_2.5PHI5_875105142005WURTH
C11: 100u/OS-CON; C_2.5PHI6.3_C6
CON1, CON2, CON3, CON4: CON_USB_UB; CON_USB_47589-0001MOLEX
CON5, CON6, CON7: CON_USB_A_614104150121; CON_USB_614104150121WURTH
GIT1: edbc0af; GIT-REVISION
I1: ICON_MINLAB_5.2S; ICON_MINLAB_5.2MM
IC1: TUSB2036; QFP32_0.8P7.2X7.2
IC2: FSUSB74MPX; QFN16_0.5P3.0X3.0
IC3, IC4, IC5: TPS2041C; IC_05_0.95_50MIL
IC6: 3.3V; DFN80P410X410_8N
IC7, IC8, IC9: 5V; DFN80P410X410_8N
IC10: SN74LVC1G139DCTR; SOT65P315X290-8N
ICON1: OSHW; ICON_OSHW
ICON2: r0.5; ICON_REVISION2.0
J1: CON_DCJACK_C1604; CON_DCJACK_C-1604
LED1: RD; CHIPLED_0805
LED2: BL; CHIPLED_0805
LED3: GR; CHIPLED_0805
LED4: YL; CHIPLED_0805
P1, P2, P3, P4: PCB_CORNER
R1, R2, R35, R36, R38, R40, R42, R43, R44: R_US__1005SHORT; R0402SHORT
R3, R4, R5, R6, R7, R8, R16, R17, R18, R19, R20, R21, R22, R23: 33/1005; C0402
R9, R10, R11, R12, R13, R14: 15k/1005; C0402
R15: 1.5k/1005; C0402
R24, R25, R31, R32, R33, R34, R37, R41, R45, R46, R47: 10k/1005; C0402
R27, R28, R29, R30: 1k/1005; C0402
R39: 10k/1005; R0402SHORT
SW1, SW2, SW3, SW4: TACTSW2_WH_SKRPACE010; SW_TACTSW_SKRPACE010
TP1: TESTPAD_4020; TP_4020
TP3, TP4, TP5: TESTPAD; TP06RECT
TP100, TP101, TP102: TESTPAD_F; FIDUCIAL
U1: LPC812M101JDH16; SOT65P510X450X110-16N
X1: TSW-106-02-S-S-RA
X2, X3, X4, X5, X6, X7: TSW-102-02-S-S
Y1: OSC4_6.0M; CLOCK_2520

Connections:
3.3V: C1.1, C2.1, C3.1, C4.1, C13.2, C14.1, C22.1, IC1.3 (VCC), IC1.25 (VCC), IC2.4 (VDD), IC6.5 (OUT), IC6.6 (OUT), IC6.7 (OUT), IC6.EP (OUT), IC10.8 (VCC), R24.2, R25.2, R27.2, R28.2, R29.2, R30.2, R31.2, R32.2, R33.2, R34.2, R35.1, R35.2 (1), R36.1, R36.2 (1), R37.1, R39.1, R39.2 (1), R41.2, R45.2, R46.2, R47.2, U1.12 (VDD), Y1.4 (VCC)
5V1: C5.1, IC3.5 (VIN), IC7.5 (OUT), IC7.6 (OUT), IC7.7 (OUT), IC7.EP (OUT)
5V2: C6.1, IC4.5 (VIN), IC8.5 (OUT), IC8.6 (OUT), IC8.7 (OUT), IC8.EP (OUT)
5V3: C7.1, IC5.5 (VIN), IC9.5 (OUT), IC9.6 (OUT), IC9.7 (OUT), IC9.EP (OUT)
!OE!: IC2.15 (!OE!), U1.1 (P0_13)
!RESET!: R24.1, U1.3 (!RESET!/P0_5), X2.1
->TX: R1.1, R1.2 (1), X1.4
<-RX: R2.1, R2.2 (1), X1.5
GND: C1.2, C2.2, C3.2, C4.2, C5.2, C6.2, C7.2, C8.-, C9.-, C10.-, C11.-, C12.2, C13.1, C14.2, C15.2, C16.2, C17.2, C18.2, C19.2, C20.2, C21.2, C22.2, C23.2, CON1.5 (GND), CON2.5 (GND), CON3.5 (GND), CON4.5 (GND), CON5.4 (GND), CON6.4 (GND), CON7.4 (GND), IC1.7 (GND), IC1.28 (GND), IC2.1 (GND), IC3.2 (GND), IC4.2 (GND), IC5.2 (GND), IC6.1 (ADJ), IC7.1 (ADJ), IC8.1 (ADJ), IC9.1 (ADJ), IC10.4 (GND), J1.1 (3), R9.1, R10.1, R11.1, R12.1, R13.1, R14.1, R38.1, R38.2 (1), R40.1, R40.2 (1), R42.1, R42.2 (1), R43.1, R43.2 (1), R44.1, R44.2 (1), SW1.1, SW1.2, SW2.1, SW2.2, SW3.1, SW3.2, SW4.1, SW4.2, TP1.TP, U1.13 (GND), X1.1, X2.2, X3.2, X4.2, X5.2, X6.2, X7.2, Y1.2 (GND)
ISP: R25.1, U1.2 (P0_12), X3.1
LSEL1: IC10.1 (1A), U1.5 (SWCLK/P0_3)
LSEL2: IC10.2 (1B), U1.6 (SWDIO/P0_2)
unnamed: IC1.1 (DP0), IC2.2 (D+), R15.1
unnamed: IC1.2 (DM0), IC2.3 (D-)
unnamed: CON1.3 (D+), R16.1
unnamed: CON1.2 (D-), R17.1
unnamed: CON2.3 (D+), R18.1
unnamed: CON2.2 (D-), R19.1
unnamed: CON3.3 (D+), R20.1
unnamed: CON4.3 (D+), R22.1
unnamed: CON3.2 (D-), R21.1
unnamed: CON4.2 (D-), R23.1
unnamed: C8.+, CON5.1 (VCC), IC3.1 (VOUT)
unnamed: C9.+, CON6.1 (VCC), IC4.1 (VOUT)
unnamed: C10.+, CON7.1 (VCC), IC5.1 (VOUT)
unnamed: IC1.30 (XTAL1/CLK48), Y1.3 (OUT)
unnamed: IC1.10 (!OVRCUR1!), IC3.3 (!FLT!), R45.1
unnamed: IC1.9 (!PWRON1!), IC3.4 (!EN!)
unnamed: CON5.2 (D-), R3.2, R9.2
unnamed: CON5.3 (D+), R4.2, R10.2
unnamed: IC1.14 (!OVRCUR2!), IC4.3 (!FLT!), R46.1
unnamed: IC1.13 (!PWRON2!), IC4.4 (!EN!)
unnamed: CON6.2 (D-), R5.2, R11.2
unnamed: CON6.3 (D+), R6.2, R12.2
unnamed: IC1.17 (!PWRON3!), IC5.4 (!EN!)
unnamed: IC1.18 (!OVRCUR3!), IC5.3 (!FLT!), R47.1
unnamed: CON7.2 (D-), R7.2, R13.2
unnamed: CON7.3 (D+), R8.2, R14.2
unnamed: IC1.6 (EEDATA/!GANGED!), R41.1
unnamed: IC1.11 (DM1), R3.1
unnamed: IC1.12 (DP1), R4.1
unnamed: IC1.15 (DM2), R5.1
unnamed: IC1.16 (DP2), R6.1
unnamed: IC1.19 (DM3), R7.1
unnamed: IC1.20 (DP3), R8.1
unnamed: IC1.27 (DP0PUR), R15.2
unnamed: IC2.13 (D0+), R16.2
unnamed: IC2.11 (D1+), R18.2
unnamed: IC2.10 (D2+), R20.2
unnamed: IC2.8 (D3+), R22.2
unnamed: IC2.14 (D0-), R17.2
unnamed: IC2.12 (D1-), R19.2
unnamed: IC2.9 (D2-), R21.2
unnamed: IC2.7 (D3-), R23.2
unnamed: IC1.32 (SUSPEND), TP5.TP
unnamed: IC10.7 (1!Y0!), LED1.C
unnamed: IC10.6 (1!Y1!), LED2.C
unnamed: IC10.5 (1!Y2!), LED3.C
unnamed: IC10.3 (1!Y3!), LED4.C
unnamed: LED4.A, R30.1
unnamed: LED3.A, R29.1
unnamed: LED2.A, R28.1
unnamed: LED1.A, R27.1
unnamed: IC1.29 (XTAL2), TP3.TP
unnamed: IC1.26 (!EXTMEM!), R35.3 (2)
unnamed: IC1.8 (!BUSPWR!), R36.3 (2)
unnamed: C23.1, IC1.4 (!RESET!), R37.2
unnamed: IC1.21 (!OCPROT!/!PWRSW!), R40.3 (2)
unnamed: IC1.31 (MODE), R38.3 (2)
unnamed: IC1.22 (NPINT1), R43.3 (2)
unnamed: IC1.23 (NPINT0), R44.3 (2)
unnamed: IC1.24 (!NP3!), R42.3 (2)
unnamed: R39.3 (2), Y1.1 (C)
unnamed: TP4.TP, U1.7 (P0_11)
SEL0: IC2.6 (SEL0), U1.14 (P0_7)
SEL1: IC2.5 (SEL1), U1.15 (P0_6)
SHIELD: CON1.SHD (SHLD), CON1.SHD$1 (SHLD), CON1.SHD$2 (SHLD), CON1.SHD$3 (SHLD), CON1.SHD$4 (SHLD), CON1.SHD$5 (SHLD), CON1.SHD$6 (SHLD), CON1.SHD$7 (SHLD), CON2.SHD (SHLD), CON2.SHD$1 (SHLD), CON2.SHD$2 (SHLD), CON2.SHD$3 (SHLD), CON2.SHD$4 (SHLD), CON2.SHD$5 (SHLD), CON2.SHD$6 (SHLD), CON2.SHD$7 (SHLD), CON3.SHD (SHLD), CON3.SHD$1 (SHLD), CON3.SHD$2 (SHLD), CON3.SHD$3 (SHLD), CON3.SHD$4 (SHLD), CON3.SHD$5 (SHLD), CON3.SHD$6 (SHLD), CON3.SHD$7 (SHLD), CON4.SHD (SHLD), CON4.SHD$1 (SHLD), CON4.SHD$2 (SHLD), CON4.SHD$3 (SHLD), CON4.SHD$4 (SHLD), CON4.SHD$5 (SHLD), CON4.SHD$6 (SHLD), CON4.SHD$7 (SHLD)
SW1: C18.1, R31.1, SW1.3 (S), SW1.4 (S), U1.11 (P0_8/XTALIN), X7.1
SW2: C19.1, R32.1, SW2.3 (S), SW2.4 (S), U1.9 (P0_1/ACMP_I2), X6.1
SW3: C20.1, R33.1, SW3.3 (S), SW3.4 (S), U1.10 (P0_9/XTALOUT), X5.1
SW4: C21.1, R34.1, SW4.3 (S), SW4.4 (S), U1.8 (P0_10), X4.1
TGT_RX: R1.3 (2), U1.16 (P0_0/ACMP_I1)
TGT_TX: R2.3 (2), U1.4 (P0_4/!TRST!)
VCC: CON4.1 (VCC)
VIN: C11.+, C12.1, C15.1, C16.1, C17.1, IC6.2 (IN), IC6.3 (IN), IC6.4 (IN), IC7.2 (IN), IC7.3 (IN), IC7.4 (IN), IC8.2 (IN), IC8.3 (IN), IC8.4 (IN), IC9.2 (IN), IC9.3 (IN), IC9.4 (IN), J1.3 (1)

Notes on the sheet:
!OE! = P0_13 SEL1 = P0_6 SEL0 = P0_7 TXT_RX = P0_0 TGT_TX = P0_4 SW1 = P0_8 SW2 = P0_1 SW3 = P0_9 SW4 = P0_10 1A = P0_3 1B = P0_2
<- UpStream(HOSTs)
DownStream(HUB) ->
CC-BY-SA
15k/1005
1k/1005
10k/1005
6~9V/2A
Mode select. When MODE is low, the APLL output clock is selected as the clock source to drive the internal core of the device and 6-MHz crystal or oscillator can be used. When MODE is high, the clock on XTAL1/CLK48 is selected as the clock source and 48-MHz oscillator or other on-board clock source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

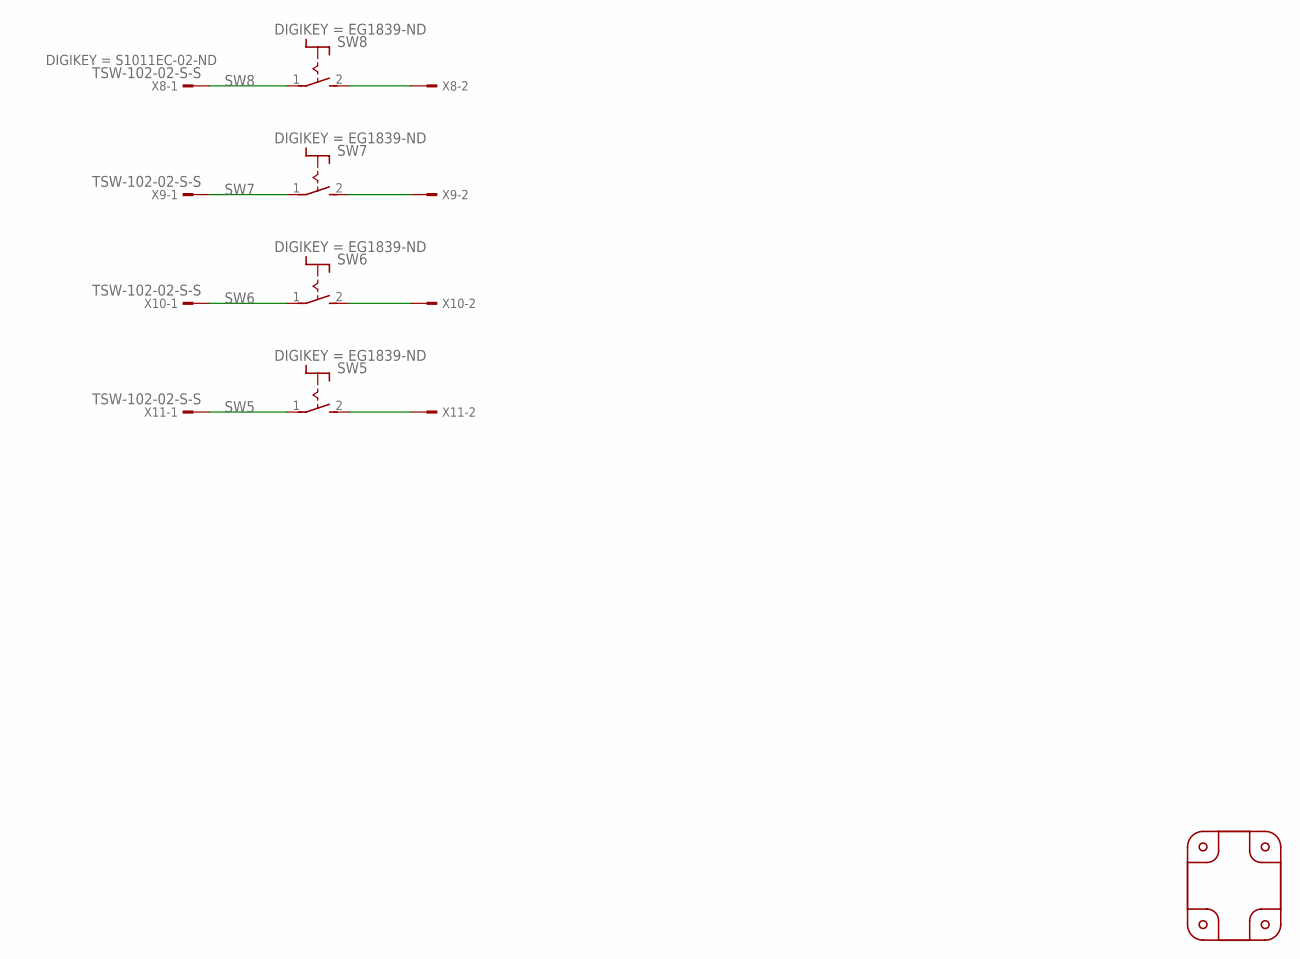
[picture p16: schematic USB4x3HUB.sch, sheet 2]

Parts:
P5, P6: PCB_CORNER
P7, P8: PCB_CORNER_NH
SW5, SW6, SW7, SW8: TACTSW2_BK_TL1105S; SW_TACTSW_TL1105S
X8, X9, X10, X11: TSW-102-02-S-S

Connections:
unnamed: SW8.2 (S), X8.2
unnamed: SW7.2 (S), X9.2
unnamed: SW6.2 (S), X10.2
unnamed: SW5.2 (S), X11.2
SW5: SW5.1, X11.1
SW6: SW6.1, X10.1
SW7: SW7.1, X9.1
SW8: SW8.1, X8.1

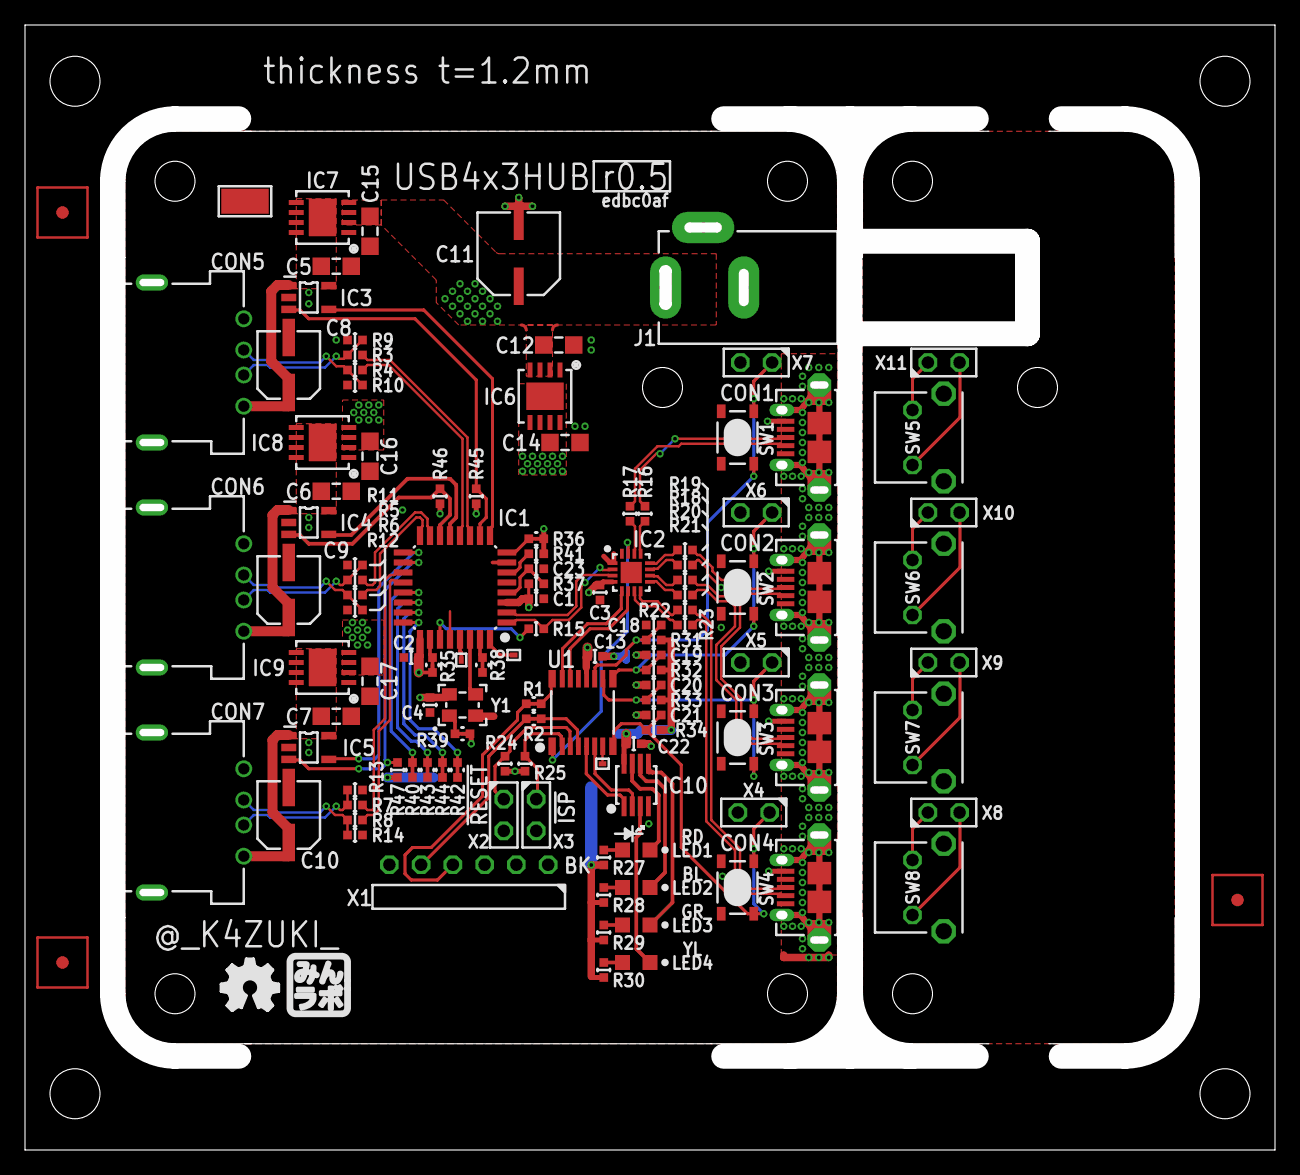
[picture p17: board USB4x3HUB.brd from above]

Board: 2 copper layers, 100.0 x 90.0 mm, 131 parts (0 on the bottom side), 92 nets.

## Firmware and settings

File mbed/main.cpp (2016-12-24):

#include <mbed.h>

DigitalOut OE(P0_13, 1);
BusOut SEL(P0_7, P0_6);

InterruptIn SW1(P0_8);
InterruptIn SW2(P0_1);
InterruptIn SW3(P0_9);
InterruptIn SW4(P0_10);
BusOut LSEL(P0_3, P0_2);

// Setup the Serial to the PC for debugging
Serial pc(P0_4, P0_0);

void SW1_int() {
  OE = 1;
  SEL = 0;
  LSEL = 0;
  OE = 0;
  pc.printf("SW1\n\r");
}

void SW2_int() {
  OE = 1;
  SEL = 1;
  LSEL = 1;
  OE = 0;
  pc.printf("SW2\n\r");
}

void SW3_int() {
  OE = 1;
  SEL = 2;
  LSEL = 2;
  OE = 0;
  pc.printf("SW3\n\r");
}

void SW4_int() {
  OE = 1;
  SEL = 3;
  LSEL = 3;
  OE = 0;
  pc.printf("SW4\n\r");
}

int main() {
  pc.baud(57600);
  pc.printf("\nHello from USB4x3HUB \n\r");

  OE = 1;
  SEL = 0;
  LSEL = 0;
  OE = 0;

  SW1.fall(&SW1_int);
  SW1.mode(PullUp);
  SW2.fall(&SW2_int);
  SW2.mode(PullUp);
  SW3.fall(&SW3_int);
  SW3.mode(PullUp);
  SW4.fall(&SW4_int);
  SW4.mode(PullUp);

  while (1) {
    wait(5);
    pc.printf(".");
  }
}

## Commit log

2015-10-28 first commit .gitignore USB4x3HUB.brd/sch
    [USB4x3HUB.brd, USB4x3HUB.sch]
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2015-10-30 BOM fix
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2015-10-30 [ FIX ] add 5V LDO on each device ports; switches moved to each host ports
    [USB4x3HUB.brd, USB4x3HUB.sch]
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2015-10-31 [ FIX ] correct some setting-pin connection
    [USB4x3HUB.brd, USB4x3HUB.sch]
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2015-11-05 [ r0.2 ] update to reflect library update
    [USB4x3HUB.brd, USB4x3HUB.sch]
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2015-11-07 [r0.2] add LEDs, add single logic 139, modify CON1-4, move silk
    [USB4x3HUB.brd, USB4x3HUB.sch]
2015-11-07 [r0.2] LED1-4/R27-30 silk
    [USB4x3HUB.brd, USB4x3HUB.sch]
2015-11-09 [r0.2] library update
    [USB4x3HUB.brd, USB4x3HUB.sch]
2015-11-14 [ r0.2 ] library update;Q1 replace;IC2 move East
    [USB4x3HUB.brd, USB4x3HUB.sch]
2015-11-16 [ r0.2 ] tCream update by library
    [USB4x3HUB.brd, USB4x3HUB.sch]
2015-11-16 [ r0.2 ][ NEW ] R35-37; tCream update; CON5-7 move; C8-10/14-16 replace size
    [USB4x3HUB.sch]
2015-11-26 update eagle version = 7.5.0; library update
    [USB4x3HUB.brd, USB4x3HUB.sch]
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2015-12-21 [ r0.3 ] move IC1 and surroundings; replace U1 to use TSSOP(JDH16); ICON_REVISION
    [USB4x3HUB.brd, USB4x3HUB.sch]
2015-12-22 [ r0.3 ] update BOM; fix HUB BUS line
    [USB4x3HUB.brd, USB4x3HUB.sch]
2015-12-24 [ r0.3 ] library update
    [USB4x3HUB.sch]
2015-12-29 [ NEW ] USB4x3HUB.csv: a BOM file
    [USB4x3HUB.csv]
2015-12-29 [ NEW ] Geber files and gerbv project file
    [USB4x3HUB.GBL, USB4x3HUB.GBS, USB4x3HUB.GTL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]
2015-12-29 [ r0.3 ] change NAME labels alignment to center; fix UART pins P0_0 and P0_4 must be used for UART as they are used by ISP
    [USB4x3HUB.brd, USB4x3HUB.sch]
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2016-01-08 library update: CON1-4 milling and IC10 attribute
    [USB4x3HUB.brd, USB4x3HUB.sch]
2016-01-29 [ NEW ] r0.3 release note detail of PCB itself and known issue(s)
2016-02-04 replace Q1 to use Oscillator add R39~45; add TP3; remove C21
    [USB4x3HUB.brd, USB4x3HUB.sch]
2016-02-04 library update; add DIGIKEY attributes
    [USB4x3HUB.brd, USB4x3HUB.sch]
2016-02-06 add C21-5,TP4,R45-7;move R16-23;OE=P0_13;add silk to point color for SW1-4
    [USB4x3HUB.brd, USB4x3HUB.sch]
2016-02-06 move some wire: library update
    [USB4x3HUB.brd, USB4x3HUB.sch]
2016-02-06 replace IC6-9 *CAUTION: airwires remain*
    [USB4x3HUB.brd, USB4x3HUB.sch]
2016-02-07 C11: library update, C5-7 moved
    [USB4x3HUB.brd, USB4x3HUB.sch]
2016-02-07 C8-11 replaced by OS-CON 16V/100uF; PCB width shrinked 10mm(and necessary moves)
    [USB4x3HUB.brd, USB4x3HUB.sch]
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2016-02-09 some trace width wider 0.2 -> 0.25mm; Capacotors re-numbering
    [USB4x3HUB.brd, USB4x3HUB.sch]
2016-02-13 IC6/R16-23,31-34,36,37,41/C1,12,14,18-23 move; LED1-4 colors
    [USB4x3HUB.brd, USB4x3HUB.sch]
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2016-02-13 library update; MinLab brand;R15
    [USB4x3HUB.brd, USB4x3HUB.sch]
2016-02-13 [ NEW ] r04 PCB pic
    [USB4x3HUB.brd, USB4x3HUB.sch]
2016-02-16 library update; PCB width shrink 2.5mm and related moves
    [USB4x3HUB.brd, USB4x3HUB.sch]
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2016-02-17 library update; panel design example in dxf layer
    MXA2-8-6SS panel marutsu.co.jp/pc/i/136286/
    [USB4x3HUB.brd, USB4x3HUB.sch]
2016-02-17 library update; [ NEW ] TB111-2-2-U-1-1 for J1 alternate
    [USB4x3HUB.brd, USB4x3HUB.sch]
2016-02-17 X1-3,R1/2 move north; J2 move - related move
    [USB4x3HUB.brd]
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2016-02-17 JUST in MXA2-8-6SS (TAKACHI)
    [USB4x3HUB.brd]
2016-02-18 [ r0.4 ] sch w/ sha1sum
    [USB4x3HUB.brd, USB4x3HUB.sch]
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2016-02-27 replace C8-10; replace CON5-7;move R27-30;move LED colors library update
    [USB4x3HUB.brd, USB4x3HUB.sch]
2016-03-05 library update; some1Ks,10Ks to use default-shorted resistors
    [USB4x3HUB.brd, USB4x3HUB.sch]
2016-03-07 SW1-4 replace to SMD package
    [USB4x3HUB.brd, USB4x3HUB.sch]
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2016-03-08 move md/csv/png to doc/
    [USB4x3HUB.csv, USB4x3HUB_r04.csv, USB4x3HUBr03.csv]
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2016-11-23 [ DOC ] add enclosure part list table
    [case1.csv]
2016-11-23 [ PCB ] prepare for panel consideration
    [USB4x3HUB.brd]
2016-11-28 [ DOC ] add case2.csv
    [case2.csv]
2016-11-28 [ DOC ] fix TITLE.md and case1.csv
    [case1.csv]
2016-12-03 [ DOC ] fix case2.csv table contents; fix instructions for 2nd enclosure idea
    TODO: primary enclosure idea requires reconsideration on panel design
    [case2.csv]
2016-12-06 library update; IC10 value updated/corrected
    - IC10 = SN74LVC1G139DCTR(was: SN74LVC1G139DCUR)
    [USB4x3HUB.brd, USB4x3HUB.sch]
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2016-12-08 a layer change from Dimention to Measures
    [USB4x3HUB.brd]
2016-12-16 [ BRD ] panel design reconsideration
    [USB4x3HUB.brd]
2016-12-17 [ BRD ] measures
    [USB4x3HUB.brd]
2016-12-17 [ PCB ] library update
    [USB4x3HUB.brd, USB4x3HUB.sch]
2016-12-17 [ PCB ] apply library update
    [USB4x3HUB.brd, USB4x3HUB.sch]
2016-12-21 correct enclosure part number
    [USB4x3HUB.brd]
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2016-12-24 [ DOC ] add another table to list additional components
    [additionalBOM.csv]
2016-12-24 fix added table
    [additionalBOM.csv]
2016-12-24 [ PCB ][ SCH ] attribute font change; attribute position change
    [USB4x3HUB.brd, USB4x3HUB.sch]
2016-12-24 [ PCB ][ SCH ] fix attributes
    [USB4x3HUB.sch]
2017-01-01 [ BRD ] library update; panel design update
    [USB4x3HUB.brd, USB4x3HUB.sch]
2017-01-31 [ PCB ] start r0.5 develop
    - remove GND terminal(TP1)
    - move switches and microB to south
    - some silk move regards to this
    - move DC jack to face on microB side
    - future: microB move to bottom side, and replace switch to panel type?
    [USB4x3HUB.brd, USB4x3HUB.sch]
2017-02-01 [ PCB ] move panel switch holes south by 1mm
    [USB4x3HUB.brd]
2017-02-01 [ PCB ] library update and related fix
    - CON5-7 pinout mistake fixed in library
    - move C8-10 to followw this change
    [USB4x3HUB.brd, USB4x3HUB.sch]
2017-02-05 [ PCB ] move C8-10; shift USB downstream traces
    [USB4x3HUB.brd]
2017-02-19 [ BRD ] fix clock mode
    - 48M source used while 6M source selected for IC
    [USB4x3HUB.brd, USB4x3HUB.sch]
2017-02-19 apply library updates; regenerate BOM
    - add SMD_PAD/TH_PAD attributes
    - update some supplier attributes
    - update BOM based on this update
    [USB4x3HUB.brd, USB4x3HUB.sch, usb4x3hub_BOM.xlsx]
2017-02-20 [ BRD ] board width is 57.0mm
    [USB4x3HUB.brd]
2017-02-21 [BRD] replace SW1-4;add pin headers for daughter board
    [USB4x3HUB.brd, USB4x3HUB.sch]
2017-02-22 [ BRD ] X4-7 pin1 connects to each switch inputs
    - move SW1-4 silk
    - move CON1-4 silk
    - move X4-7 silk
    - add 2.8mm hole for M2.6 screw
    - add tRestrict zone for it
    [USB4x3HUB.brd, USB4x3HUB.sch]
2017-02-22 [ BRD ] clean ratsnest
    [USB4x3HUB.brd]
2017-02-22 [ PCB ] add sheet for daughter board; move M2.6 hole; library update
    - prepare daughter board
    - apply updated library and use TACTSW2 component
    - more consideration required
    [USB4x3HUB.brd, USB4x3HUB.sch]
2017-02-22 [ PCB ] update library; remove south M2.6 hole; update panel design to reflect design change
    [USB4x3HUB.brd, USB4x3HUB.sch]
2017-02-27 [ PCB ] library update etc.
    - SW assy on top
    - make room for DC jack
    [USB4x3HUB.brd, USB4x3HUB.sch]
2017-02-27 [ BRD ] increase room for DC jack; use M3 instead of M2.6
    - I have quite many M3 spacers
    [USB4x3HUB.brd]
2017-02-27 [ BRD ] update panel design
    - DC jack height is 11mm instead of 10mm
    [USB4x3HUB.brd]
2017-02-28 [ DOC ] updates for document
    [USB4x3HUB_r04.csv]
2017-03-04 [ DOC ] update doc and BOM
    [additionalBOM.csv]
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2017-07-31 update panel width; fix DRC ererror
    [USB4x3HUB.brd]
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2017-08-01 update Makefile-s
    - root/Makefile:
    - remove comments
    - add $(MAKE) variable to switch make command
    - doc/Makefile:
    - defines only minimum set of global variable
    - defines project specific variables
    - removes all other duplicated part
    - includes Makefile.in and Makefile from pandoc_misc
    - doc/Makefile.in:
    - no longer used - to be removed
2017-08-07 library update; rename Q1 to Y1
    [USB4x3HUB.brd, USB4x3HUB.sch]
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2017-08-08 rename BOM table and moved into data directory
    [BOM-r0.5.csv]
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2017-08-08 update milling and drill
    - replace by 2.8mm drill hole
    - for M2.6 spacer
    - extend DC jack milling
    [USB4x3HUB.brd]
2017-08-08 sub board has corner holes on connector side
    - add shield vias
    - back to 3.2mm hole
    [USB4x3HUB.brd, USB4x3HUB.sch]
